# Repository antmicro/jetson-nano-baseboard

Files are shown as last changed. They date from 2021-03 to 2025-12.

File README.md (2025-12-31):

# Jetson Nano Baseboard

Copyright (c) 2020-2025 [Antmicro](https://www.antmicro.com)



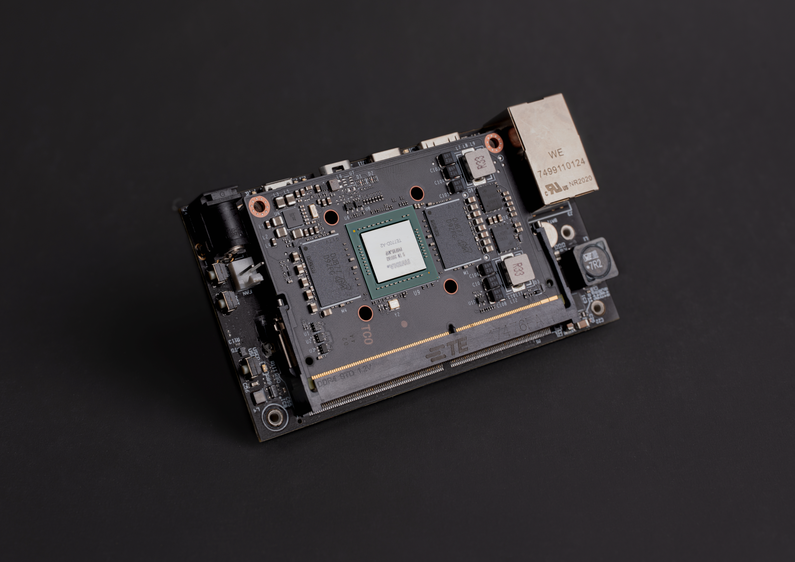
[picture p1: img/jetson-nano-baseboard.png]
Jetson Nano Devboard


## Overview

This project contains open hardware design files for a baseboard supporting the NVIDIA Jetson Nano, Xavier NX and TX2 NX SoMs.
It was created by [Antmicro](https://antmicro.com), a custom hardware, software and AI engineering company and NVIDIA's Jetson ecosystem partner.
The board can be interfaced with MIPI CSI-2 video devices through a unified Flexible Flat Cable (FFC) connector, supporting up to 4 sensors in a 2-lane configuration or 3 sensors in a 4-lane configuration.
Please refer to the Product Design Guide for the relevant SoM for more details regarding the supported CSI lane mappings.
You will find the SoM-related resources in NVIDIA's [Jetson Download Center](https://developer.nvidia.com/embedded/downloads). 

The design files for this project starting from Rev. 1.5 are provided and maintained in KiCad.
Older revisions of the board were prepared in Altium Designer and are kept on a separate [branch](https://github.com/antmicro/jetson-nano-baseboard/tree/1.4.7-altium).

### Project structure:

The main directory contains the KiCad design files, LICENSE and README.
The remaining files are stored in the following directories:

* ``img`` - contains graphics for this README
* ``linux-patches`` - contains patches which add camera support for camera modules from Allied Vision (see the BSP section below)

## Key features

* Jetson Nano / Xavier NX / TX2 NX SO-DIMM connector
* Gigabit Ethernet RJ45 connector
* Micro USB debug connector
* USB-C DFP (Host) port
* Micro HDMI video output interface
* Mini DisplayPort video output interface
* 2x 50-pin FFC connectors exposing up to 4 MIPI CSI-2 camera interfaces
* M.2 (key M) connector exposing PCIe x4 interface
* RTC battery backup
* EEPROM for storing board ID/SN
* 100x55mm (3.93 x 2.16 inch) mechanical outline 

## Getting started

The board can be produced and assembled using the provided design files.
Please take a look at the mechanical layers for more information regarding the PCB stackup recommended for fabrication.
The board can be powered by a voltage in the 6-36VDC range.
It is recommended to use a 12V 2A DC supply to power the board.
The board has an integrated power sequencer that starts the module automatically right after applying power supply.

### BSP

The baseboard's I/O interfaces are supported in the standard [Linux for Tegra (L4T) BSPs](https://developer.nvidia.com/embedded/linux-tegra) provided by NVIDIA for Jetson Nano / Xavier NX / TX2 NX. 
The BSP should work with the Open Source Jetson Baseboard out of the box.
However, to use the baseboard with various cameras and other accessories you may need to make modifications.
If you plan to use the board with Allied Vision [Alvium](https://www.alliedvision.com/en/products/embedded-vision-solutions/alvium-camera-modules-for-embedded-and-machine-vision-applications.html) image sensors, there is a ``linux-patches`` directory, which contains patch files that add support for the Allied Vision cameras for this baseboard with the Jetson Nano NX module.
The patches are named with the L4T release and can be applied to the corresponding branches of the Linux [repository](https://github.com/alliedvision/linux_nvidia_jetson) released by Allied Vision. 
Antmicro's services involve BSP development so you can hire us to make the necessary modifications for you.

You can use the USB OTG interface connector to upload a BSP image to a SoM inserted into the baseboard.

### Debug UART connection

Most of the debug messages are provided through the serial console.
The board includes an FTDI chip providing the UART interface to the host PC.
Please refer to the schematic sheets for more details.
The default debug UART channel is accessible through ``/dev/ttyUSB0`` (assuming that there are no other FTDI units connected to your PC).
The default baudrate for serial debug connection is 115200 baud with an 8-bit transmission, 1 stop bit and with no flow control.

### Revision info

1.5.x revision includes the design files converted into KiCad.
The BOM has been altered so the board can be produced despite the global chip shortage situation.
Revision 1.5.x changes the I2C multiplexer (PCA9548 -> PCA9547) used for handling the cameras and video accessories. 
You may need to adjust the devicetree entries for video accessories to make them work with the new I2C multiplexer chip.

## License

This project is licensed under the [Apache-2.0](LICENSE) license.

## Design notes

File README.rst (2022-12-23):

=======================================
Antmicro's Open Source Jetson Baseboard
=======================================

Copyright (c) 2020-2022 `Antmicro <https://www.antmicro.com>`_





Overview
========

This repository contains open hardware design files for a baseboard supporting the NVIDIA Jetson Nano, Xavier NX and TX2 NX SoMs. It was created by `Antmicro <https://antmicro.com>`_, a custom hardware, software and AI engineering company and NVIDIA's Jetson ecosystem partner.
The board can be interfaced with MIPI CSI-2 video devices through a unified Flexible Flat Cable (FFC) connector, supporting up to 4 sensors in a 2-lane configuration or 3 sensors in a 4-lane configuration.
Please refer to the Product Design Guide for the relevant SoM for more details regarding the supported CSI lane mappings. You will find the SoM-related resources in NVIDIA's `Jetson Download Center <https://developer.nvidia.com/embedded/downloads>`_. 

The baseboard, its custom variants designed by Antmicro per customer's specification, and essential accessories can be purchased from `Capable Robot Components <https://capablerobot.com/products/nx-baseboard/>`_.

The design files for this project starting from Rev. 1.5 are provided and maintained in KiCad.
Older revisions of the board were prepared in Altium Designer and are kept on a separate `branch <https://github.com/antmicro/jetson-nano-baseboard/tree/1.4.7-altium>`_.

Repository structure:
---------------------

The main repository directory contains the KiCad design files, LICENSE and README.
The remaining files are stored in the following directories:

* ``img`` - contains graphics for this README
* ``doc`` - contains generated schematics and other documentation
* ``lib`` - contains KiCad component library
* ``linux-patches`` - contains patches which add camera support for camera modules from Allied Vision (see the BSP section below)

Key features
============

* Jetson Nano / Xavier NX / TX2 NX SO-DIMM connector
* Gigabit Ethernet RJ45 connector
* Micro USB debug connector
* USB-C DFP (Host) port
* Micro HDMI video output interface
* Mini DisplayPort video output interface
* 2x 50-pin FFC connectors exposing up to 4 MIPI CSI-2 camera interfaces
* M.2 (key M) connector exposing PCIe x4 interface
* RTC battery backup
* EEPROM for storing board ID/SN

Getting started
===============

The board can be produced and assembled using the provided design files.
Please take a look at the mechanical layers for more information regarding the PCB stackup recommended for fabrication.
The board can be powered by a voltage in the 6-36VDC range.
It is recommended to use a 12V 2A DC supply to power the board.
The board has an integrated power sequencer that starts the module automatically right after applying power supply.

BSP
---

The baseboard's I/O interfaces are supported in the standard `Linux for Tegra (L4T) BSPs <https://developer.nvidia.com/embedded/linux-tegra>`_ provided by NVIDIA for Jetson Nano / Xavier NX / TX2 NX. The BSP should work with the Open Source Jetson Baseboard out of the box. However, to use the baseboard with various cameras and other accessories you may need to make modifications. If you plan to use the board with Allied Vision `Alvium <https://www.alliedvision.com/en/products/embedded-vision-solutions/alvium-camera-modules-for-embedded-and-machine-vision-applications.html>`_ image sensors, there is a ``linux-patches`` directory, which contains patch files that add support for the Allied Vision cameras for this baseboard with the Jetson Nano NX module.
The patches are named with the L4T release and can be applied to the corresponding branches of the Linux `repository <https://github.com/alliedvision/linux_nvidia_jetson>`_ released by Allied Vision. 
Antmicro's services involve BSP development so you can hire us to make the necessary modifications for you.

You can use the USB OTG interface connector to upload a BSP image to a SoM inserted into the baseboard.

Debug UART connection
---------------------

Most of the debug messages are provided through the serial console.
The board includes an FTDI chip providing the UART interface to the host PC.
Please refer to the schematic sheets for more details.
The default debug UART channel is accessible through ``/dev/ttyUSB0`` (assuming that there are no other FTDI units connected to your PC).
The default baudrate for serial debug connection is 115200 baud with an 8-bit transmission, 1 stop bit and with no flow control.

Revision info
-------------

The latest revision of the board (1.5.x) includes the design files converted into KiCad.
The BOM has been altered so the board can be produced despite the global chip shortage situation.
Revision 1.5.x changes the I2C multiplexer (PCA9548 -> PCA9547) used for handling the cameras and video accessories. You may need to adjust the devicetree entries for video accessories to make them work with the new I2C multiplexer chip.

License
=======

`Apache-2.0 <LICENSE>`_

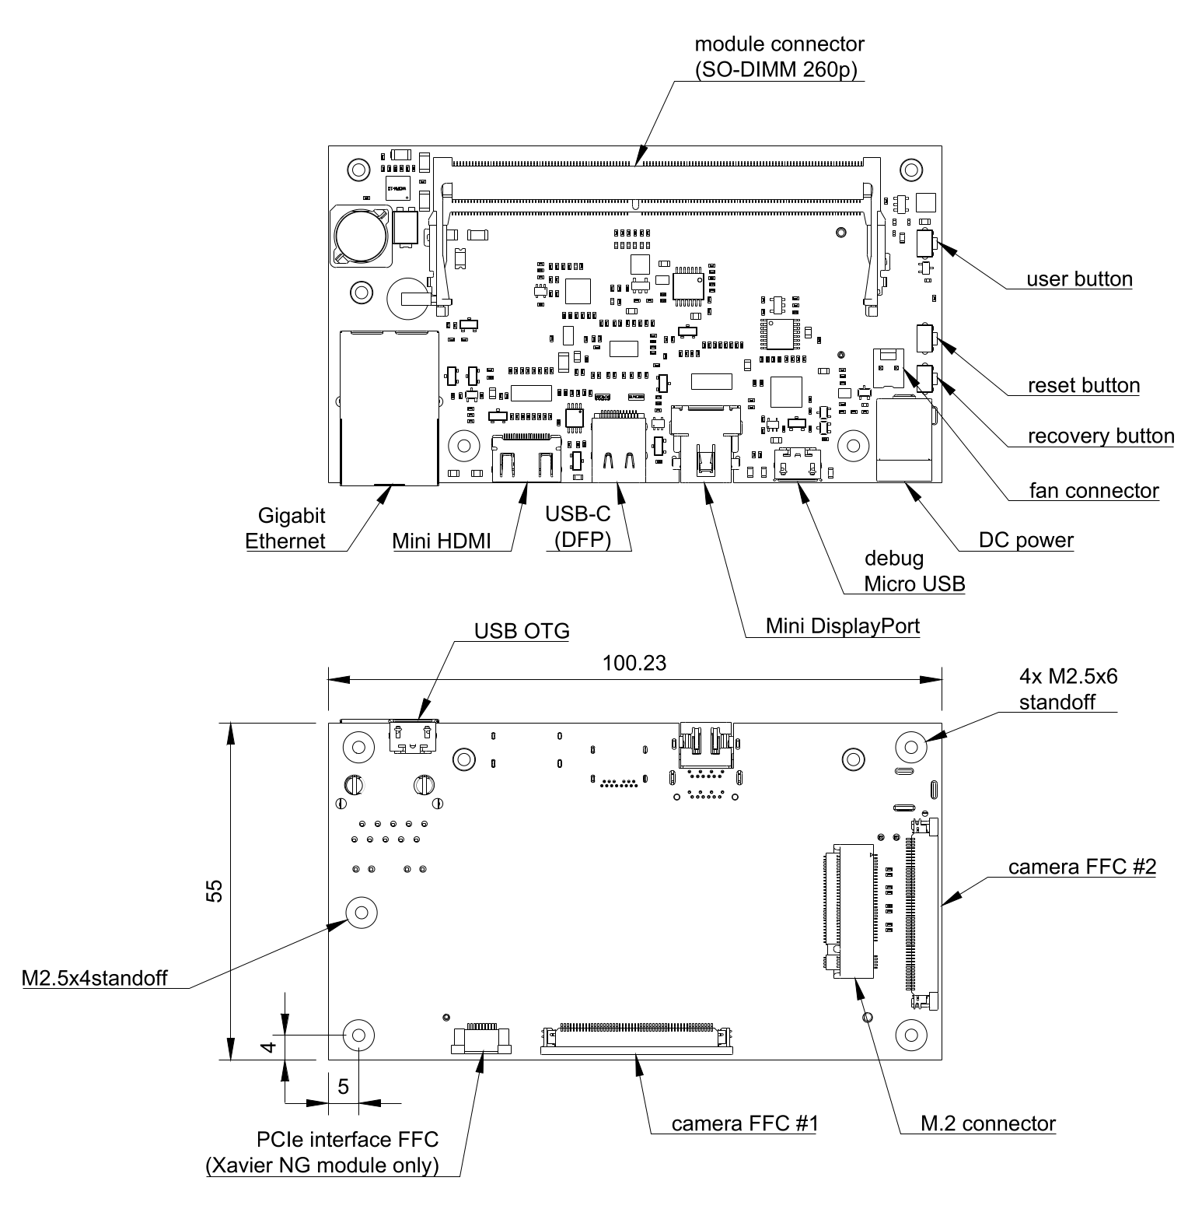
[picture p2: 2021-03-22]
img/jetson-nano-layout.png

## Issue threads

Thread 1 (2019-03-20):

where can find and download this linux system ?

cudnn, 2019-03-20:
where can find and download this linux system ?

pkatarzynski, 2020-04-29:
Most of the IO interfaces available on board are supported by the default BSP provided by Nvidia
See https://developer.nvidia.com/embedded/downloads for more details.

MI-LA01, 2020-11-06:
@pkatarzynski  : Just brought one unit via capable robot for testing. When you said "Most of the IO.." can you elaborate a bit more on that ? What are the IOs not supported by the BSP if any ?

pkatarzynski, 2020-11-06:
You  will most likely need to adjust the BSP for camera (CSI) interfaces. The Ethernet, USB-C, HDMI, Displayport, M.2 (NVMe) are handled by the default JetPack provided by NVIDIA for the Jetson Nano or the Jetson Xavier NX

MI-LA01, 2020-11-06:
Any Guidance/doc to tune the BSP for the 2x 50-pin FFC and 10-pin FFC PCIe x1 ?

Closed 2020-04-29.

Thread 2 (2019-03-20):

how make the usb 3 in device mode?

cudnn, 2019-03-20:
how make the usb 3 in device mode?how pitch the linux kernel ?how reconfigure type c hardwire?

mgielda, 2022-05-07:
I will close this one now - these are very generic questions which are not related to the baseboard itself but rather to Linux/NVIDIA Jetpack. For future reference, we do offer commercial support for customers who need help building software, if you require it please contact us at contact@antmicro.com

Closed 2022-05-07.

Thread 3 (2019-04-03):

PCB files

kfriesth, 2019-04-03:
Would you export the pcb schematic and pcb layout files to kicad or gerber file formats?

qume, 2020-03-17:
Perhaps a bit late, but there is a free online Altium viewer here:

[https://www.altium.com/viewer/](https://www.altium.com/viewer/)

Drag and drop the schdoc files, and it will show you the schematic, the BOM, and in the case of the PCB file, the layout

I'll be starting a KiCAD board for the nano soon, did you end up doing one? Any interest in sharing the project?

pkatarzynski, 2020-04-29:
We have a KiCad version of this board converted from Altium files. We hope to share this version soon.

qume, 2020-04-29:
@pkatarzynski great news, thanks very much. Looking forward to it

AdrianCGonzalez, 2020-06-11:
Would it be possible to export the Altium PCB files to ASCII format?

wgthompson, 2021-03-26:
Longshot but any chance we can get the files in eagle?

wild929, 2021-09-15:
I am using Altium Circuit Studio and am unable to import the PCB layout. Is there a way that you can save the file as  a PCB 5.0 Binary file?

Cheers...

pgielda, 2021-09-15:
Not sure if that helps but there is a branch with Kicad version: https://github.com/antmicro/jetson-nano-baseboard/tree/kicad-version

wild929, 2021-09-15:
> Not sure if that helps but there is a branch with Kicad version: https://github.com/antmicro/jetson-nano-baseboard/tree/kicad-version

Thanks. I am downloading KiCad now in the hopes I can convert the file to PCB Binary 5. I really don't want to have to get up to speed on a new tool.

wild929, 2021-11-08:
Perhaps a bit off topic but can you tell me if the TX2 NX 's USB3 (which is 3.0) and USB1 (2.0) port can be connected directly to a USB3.0 Type A port? Or does this connection require a controller / mux between SOM and port?

Thanks.

pkatarzynski, 2021-11-08:
It is possible to connect the USB lanes you mentioned directly to an USB 3.0 type-A port.

mgielda, 2022-05-07:
As the main branch has switched to KiCad now, this issue can now be closed.

Closed 2022-05-07.

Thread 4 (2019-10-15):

Capacitors on the BOM

S4WRXTTCS, 2019-10-15:
Some of the caps seem to be undersized for the expected voltages.  As an example C1, C2, C3, C4 are shown in the BOM as Murata Electronics P/N: GRM155R60G475ME

That's a 4V part, but C1 along with C2 are connected to HDMI_PWR which has 5V going to it.

Other caps are under the expected voltages, but only barely so. There doesn't seem to be any capacitor de-rating used when creating the BOM.

pkatarzynski, 2019-10-16:
Hi Jason

Thank you for your contribution. We are going to revise the BOM and update the capacitors for a bigger range of rated voltages.

Closed 2019-10-16.

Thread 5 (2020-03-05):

The new PCB doesn't match with the schematic

sunzhongmeng, 2020-03-05:
hello ,i found the new pcb add a M.2 sloat,but the i can't find it in schematics.

pkatarzynski, 2020-03-06:
Hi sunzhongmeng

The M.2 connector (J10) has been defined in interfaces.SchDoc file which has been accidentally excluded from the main project file (PrjPcb). We have fixed the project file.
Thank you for spotting this.

sunzhongmeng, 2020-03-06:
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

Hello Piotr
I fetch the project you have update,yes I see the "Interfaces.SchDoc",I'm sorry to talk about the SD/MMC card,the README file shows the board has a SD/MMC card(the assembly pdf also shows the J8),I didn't see it in the Project files(neither schematics or pcb layout file)

pkatarzynski, 2020-03-06:
This should now be resolved.

Closed 2020-03-06.

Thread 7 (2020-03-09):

HDMI pull down resistors

sunzhongmeng, 2020-03-09:
Hello ，the NVIDIA Jetson Nano Product Designe Guide  says "499Ω, 1% pull-downs must be disabled when Jetson Nano is off or in sleep mode to meet the HDMI VOFF requirement. The enable to the FET, enables the pull-downs when the HDMI interface is to be used"but this design delete all pull down resistors.does it work well?

pkatarzynski, 2020-03-09:
We have simplified some of the interfaces to gain more space for routing and make the PCB smaller. The board is meant to work as technology demonstrator and evaluation platform which stays in always-on mode. Hence satisfying HDMI VOFF was not our priority. The PCBs in rev. 1.3 were displayed at our booth during Embedded World 2020 in [camera related application](https://www.linkedin.com/posts/antmicro-ltd_jetsonnano-xaviernx-opensource-activity-6638028555051638785-Hmo-/)

sunzhongmeng, 2020-03-09:
> We have simplified some of the interfaces to gain more space for routing and make the PCB smaller. The board is meant to work as technology demonstrator and evaluation platform which stays in always-on mode. Hence satisfying HDMI VOFF was not our priority. The PCBs in rev. 1.3 were displayed at our booth during Embedded World 2020 in [camera related application](https://www.linkedin.com/posts/antmicro-ltd_jetsonnano-xaviernx-opensource-activity-6638028555051638785-Hmo-/)

I see ，thank u.

Closed 2020-03-09.

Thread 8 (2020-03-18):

the width of the VIN to TPS54561

sunzhongmeng, 2020-03-18:
The copper of the top layer is 0.035mm,the width of VIN tracks to the TPS54561 is 0.4mm,the power need atlest 5V*4A=20W,so i think the current of VIN is 20W/12V=1.67A,The width seems not enough

pkatarzynski, 2020-03-18:
Hi sunzhongmeng
Thank you for spotting this. We are currently working on rev 1.4 of the design.  The PCB layout has been modified and power distribution planes have been widened accordingly to the expected current density. I hope to update the design files after verification on prototypes.

sunzhongmeng, 2020-03-18:
OK,I got it.because the NX's power dissipation will be 15W,perhaps the +5V supply will more the 5A .

Closed 2020-04-01.

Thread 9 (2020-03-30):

Pin Error of TPD8S009

sunzhongmeng, 2020-03-30:
The VCC pins of the TPD8S009 are Pin 13 and Pin15,not Pin14.

pkatarzynski, 2020-03-30:
Hi sunzhonmeng

You are right, the TPD8S009 chip is still to power supply via pin13 and pin14 (which is effectively a NC pin) in the design so it worked properly on prototypes. Nevertheless the pin to pad assignment in this component needs to be fixed.
Thank you for spotting this.

Closed 2020-04-01.

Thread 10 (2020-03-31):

Power sequensing

gudozhni, 2020-03-31:
Hello!

This might not be an issue, but something in your design contradicts Nvidia information.
It would be great if you could clarify it.
1) The datasheet expressly states that no signals should be applied to any module IO pin until it's completely powered up. To obtain such behavior, the evalkit design enables carrier power supplies (3.3, 1.8) with SYS_RESET, which goes high when module finished power up process. In your design, these power supplies are enabled by POWER_GOOD of the main 5V DC/DC, so they are enabled at the same time as 5V_SYS. You did it like that because it JUST WORKS and you don't see any adverse effect or I'm missing something?
2) According to the graph on the page 9 of the Jetson Nano Product Design Guide, in case of sudden power loss the main power supply should decay from 5V to 3V no faster than at least 10ms, to allow shutting down the module gracefully after servicing SHUTDOWN_REQ and forcing POWER_EN low. The three 47uF caps on the 5V rail in your design would only last for ~50us before the voltage drops to 3V. So the evident question here is - did you have any troubles with hard power offs? Did you test such cases?

I'd be very grateful for any info on the 2 points above!

Best,
Olex

pkatarzynski, 2020-03-31:
Hello Olex

Thank you for your contribution.

As for the 1. this has been already discussed. We are going to release a new PCB revision which uses
SYS_RESET for starting the on-board peripherals. Nevertheless using POWER_GOOD to start the DC/DC worked for us so far as well.

As for 2. we have already done a couple of technology demonstrators using this board. Theese included (multi-) camera setups showcased during the last Embedded World. Most of those setups were powered off by disconnecting the main power supply. This by no means affected the module or software running on it. We will take a look at the voltage decay - we will record this curve on oscilloscope to have a real-life example for further analysis.

gudozhni, 2020-04-01:
Hello Piotr,
thanks a lot for your explanations! that is sufficient for me.

Closed 2020-04-01.

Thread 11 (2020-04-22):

the max dissipation of the nx module

sunzhongmeng, 2020-04-22:
hello,in the latest version i found the supply is tps54561,the max current is 5A,assume the nx module work in 15W model and the USB device need 2A current ,it seems the supply can't provide enouth current.By the way ,dit the new version of the board has been verified?

pkatarzynski, 2020-04-29:
The on-board DC/DC is indeed tailored for 25W. The total power consumption of the Jetson Xavier NX and peripheral interfaces (USB devices or CSI cameras) need to fit within this range. This board is mostly a technology demonstrator. It does not cover all of the possible usage scenarios.
We have tested the prototypes for release 1.4.2. You can check out  our latest blog release in that matter.
https://antmicro.com/blog/2020/04/updated-jetson-nano-xavier-nx-baseboard-m2/
We hope to describe some more integrations soon.

Closed 2020-04-29.

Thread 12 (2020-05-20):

Manufacturing of the board / readily availbale boards for sale?

careyer, 2020-05-20:
Hi there,

thank you very much for taking all the effort and time to make this incredible and compact carrier board. What would be the best way to get one produced (any recommendations of manufacturers that can easily process the available design files?) or maybe is there somebody arround with a ready made spare board that he wants to sell?

Thank you very much and sorry for poluting the issues section =)

sunrise-ceo, 2020-05-22:
Supporting the question above. Would love to buy a couple of ready-made baseboards as well, for testing at first, but, potentially, for mass production of our products. Are there any online retailers (or maybe factories, accepting orders for production) who have this baseboard in stock? Thanks in advance.

kalvdans, 2020-11-09:
Is this fixed by https://github.com/antmicro/jetson-nano-baseboard/commit/56bf3e57818304ef53ff78908ac0a93a50a09229, @pkatarzynski ?

osterwood, 2020-11-17:
Yep!  Baseboards are available for purchase on the Capable Robot website.

https://capablerobot.com/products/nx-baseboard/

Stock on the initial batch is nearly sold out.  A much larger batch is being made now and will take about a month produce.

mgielda, 2020-12-01:
Thanks for answering this, Chris @osterwood :)

Indeed Capable Robot is selling them now, so I consider the issue closed.

Closed 2020-12-01.

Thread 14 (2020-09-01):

buck capacitors for the Jetson NX SOM

sunzhongmeng, 2020-09-01:
the Jetson NX Developer Kit has three capacitors(C145/C146/C147 330uF) for the SOM +5V power supply.But this design just placed two 100uF capacitors (C10/C11),by the way the MLCC has 'DC Bias' character,at +5V the capacitor will be reduce.I have my own carrier board has only two buck capacitors(two 100uF),when i run some programs to test the GPU load the board will be closed(because of the +5V supply droped below 4.75V).

pkatarzynski, 2020-09-11:
We were testing the Jetson Nano Baseboard with NVIDIA Jetson Xavier NX installed and a bunch of benchmarks from https://github.com/NVIDIA-AI-IOT/jetson_benchmarks. This setup worked stable for us.
Please note that the main power supply for the board should be over 5V DC (we have 9V DC suggestion on schematics) to make the on-board DC/DC converter produce 5 VDC required for the SoM.
The board is compact-sized so we are limitted in PCB space available for the filtering capacitors. We are planning to squeeze more of them in the next revision.

Closed 2020-09-27.

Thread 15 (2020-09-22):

Any update on Kicad files?

BlueWaterCrystal, 2020-09-22:
what stage are the Kicad files currently at?

#3
> We have a KiCad version of this board converted from Altium files. We hope to share this version soon.

tkircher, 2020-11-17:
I'd like to know too. I'm interested in a board with this form factor, but stripped down to the SoM connector, DC power, M.2 connector, USB 3.0, and debug port. Would be nice if I could route that in four layers and get it made at OSHpark. ;)

vanbwodonk, 2020-11-19:
I'm waiting for this too.

ncx94, 2021-03-08:
Hi,

Definitely would be interrested in that too!

abhibhatia98, 2021-05-07:
Hello Everyone, I am working on the same project, and completed the schematic and PCB is going to be completed in 2 more days. Any one here who is experienced PCB designer and is interested in this project and who can review my PCB are welcome. I am ready to share project. It will be helpful for other also.

PS: I am not an experienced PCB designer for high speed designs.
Thanks

tkircher, 2021-05-07:
One big advantage of the Jetson SoM is that most of the critical high speed design is done for you.

ncx94, 2021-05-07:
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

Awesome thank you! Not a professional either but I'd be happy to have a look at it! :)

pkatarzynski, 2021-05-07:
We are working on the KiCad version. The design files will be released soon.

ncx94, 2021-07-21:
> We are working on the KiCad version. The design files will be released soon.

Hi,

Any updates on that?

Thanks

pkatarzynski, 2021-08-18:
Please take a look at the branch https://github.com/antmicro/jetson-nano-baseboard/tree/kicad-version

Closed 2021-08-18.

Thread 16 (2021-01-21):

Problem with the HDMI

baroselfdriving, 2021-01-21:
HI. we are working with a modified version of your board adding other peripherals.
We have a problem with the HDMI. The board recognise correctly the MONITOR. But I don't have video, any monitor say: NO SIGNAL. But when I connect the HDMI cable the VNC adjust the resolution automatically with the new monitor.

I review all the design and is the HDMI area is exactly your design.

I installed the last l4t version 4.5 and didn't work. I used the previous and when boot appear not good defined the NVIDIA LOGO. Now I downgrade other version and I can see distorted the image with the initial SETUP of UBUNTU.
Some suggestions?

I'm attaching the dmesg:

27.961495] extcon-disp-state extcon:disp-state: cable 47 state 1
[   27.961501] Extcon AUX1(HDMI) enable
[   27.961902] extcon-disp-state extcon:disp-state: cable 51 state 1
[   27.961905] Extcon HDMI: HPD enabled
[   27.961947] tegradc tegradc.0: hdmi: plugged
[   27.971100] tegradc tegradc.0: blank - powerdown
[   28.026888] extcon-disp-state extcon:disp-state: cable 47 state 0
[   28.026890] Extcon AUX1(HDMI) disable
[   28.047209] tegradc tegradc.0: unblank
[   28.058165] tegradc tegradc.0: nominal-pclk:148500000 parent:148500000 div:1.0 pclk:148500000 147015000~161865000
[   28.058250] tegradc tegradc.0: hdmi: tmds rate:148500K prod-setting:prod_c_hdmi_75m_150m
[   28.059266] tegradc tegradc.0: hdmi: get RGB quant from EDID.
[   28.059273] tegradc tegradc.0: hdmi: get YCC quant from EDID.
[   28.097834] extcon-disp-state extcon:disp-state: cable 47 state 1
[   28.097839] Extcon AUX1(HDMI) enable
[   28.098118] tegradc tegradc.0: unblank
[   28.098125] tegradc tegradc.1: blank - powerdown
[   28.139675] tegradc tegradc.0: unblank
[   28.139834] tegradc tegradc.1: blank - powerdown

Best Regards

Gabriel

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

ahmetcanack, 2021-04-26:
Are you using the correct SOM, I believe there are 2 versions of modules, [You can see the differences here.](https://www.arducam.com/nvidia-jetson-nano-b01-update-dual-camera/)

I have also seen people designing custom carrier boards with the help of the documentation shared by Nvidia.  They were having problems with the ethernet. There is a lot of confusion about this.  Maybe this has to do something with your problem.

Jslater85, 2021-08-18:
Hi, I have encountered similar problems as mentioned  by Gabriel.

Did you ever have any resolution to this issue with the HDMI?

Which SOM is the correct to use?

All the best!

Jake

baroselfdriving, 2021-08-18:
We finally redesign the hdmi lanes to prevent the issue, following the rules of the hdmi design and we used the jetson carrier board to solve many small issues.
About the firmware for 4 cameras, finally we design it based in the e3333 dts in the jetpack and we have it published in our website.

Best regards

Gabriel Giani

pkatarzynski, 2021-08-18:
Hi all, HDMI works properly on the original design and many derivatives we have been building. If you redesign the board yourself and you cannot get something to work on the derivative design, this is not something we can help with. If you need help to build your own board, feel free to reach out to us to use our commercial services.

Closed 2021-08-18.

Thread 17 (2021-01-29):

Routing layers copper pours

iDevMartin, 2021-01-29:
I noticed the signal/routing layers in the layout do not contain large GND copper pours, is there a reason it was not added to the design? Shouldn't it help with impedance control and shielding?

ajawamnet, 2021-04-01:
In some cases it can lead to uncontrolled CPW - coplanar wave guides -
https://en.wikipedia.org/wiki/Coplanar_waveguide

https://www.microwavejournal.com/blogs/1-rog-blog/post/24374-comparing-microstrip-and-grounded-coplanar-waveguide
In the newer versions of altium the simbeor LSM will "sort of" calculate these.   Use of CPW also requires careful consideration of via stiching to the contiguous  reference plane

Regardless, using copper pours is typically not recommended except in certain situations.  As to using it for thieving note what Lee Ritchey states here:
https://ee-training.dk/pcb-manufacturing/copper-thieving-confusion.htm

" If the next layer down is a plane layer,
that is all that is needed. If the next layer down is a signal layer (buried
microstrip) thieving should not be placed over traces in the buried
layer."

I have to agree - I've designed over 3,000 PCB's of various complexities and the only times I've had to use copper pours was for either current requirements or CPW to reduce trace widths to match tiny RF connectors. And the latter is a pain due tot he stitching requirements

Broadcom has a nice, free calculator that has CPW:
https://www.broadcom.com/appcad
This is a later version of the original HP calculator. If you go into the CPW part you can see the effect of having copper pours edge coupling to traces.

And using copper pours on internal layers can lead to split plane issues that cause discontinuities in reference to things like controlled impedance traces - ESP if you are using asymmetric striplines.

mgielda, 2022-05-07:
Since this was explained quite a while ago, I think we can close the issue.

Closed 2022-05-07.

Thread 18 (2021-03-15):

Buffer for driving PWR_EN

yamiyukiharu, 2021-03-15:
Hi, May I know if anyone has tried driving PWR_EN from IC12 instead of IC13?

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

wild929, 2021-12-06:
My understanding of this circuit is that the R84/C41 time constant, and subsequent rise time of the 1A input, is slow enough to make Q = 1 on 5V0_SYS approaching 5V. At this point PWR_EN is latched until #SHUTDOWN_REQ is driven low by the TX2 NX module. Is this correct? What is the purpose of PWR_GOOD? What would be the benefit of driving PWR_EN from IC12 /R130? Response time?

Cheers!

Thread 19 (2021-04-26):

Use of below circuitry

abhibhatia98, 2021-04-26:
Hi I am just looking at your circuit, could you please help me to understand the use of below circuit in supply sheet

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

Thanks
Abhishek

ahmetcanack, 2021-04-26:
Hi, if you look at chapter 5.1 Power Supply and Sequencing in the jetson nano product design guide, you will see a power sequencing graph. Basically, power must not be delivered without control, for some power rails to be enabled, other rails or ok signals must be checked and validated. This circuit makes sure that these enable signals are generated correctly following the power sequencing requirements in the jetson nano product design guideline. I suggest you read the first paragraph in chapter 5.1. There is a nice explanation for all this. And also you might check out how nand gates work. In terms of schematic layout i find this particular layout a bit clustered. But its not impossible to understand. This 4x NAND IC could have been seperated as four individual schematic symbols each showing a NAND symbol. That way it could have been easier for all to read. Lastly this is a great project for individuals to create their custom , and you will find it easier if you go through the product design guide.

abhibhatia98, 2021-04-26:
Thanks for your response, it helps me a lot

Closed 2021-04-26.

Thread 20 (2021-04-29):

Booting board

abhibhatia98, 2021-04-29:
Any specific reasons of removing SD card socket ?

where you will residing your OS ?

ahmetcanack, 2021-04-29:
Jetson Nano SoM has onboard eMMC and sd card socket.

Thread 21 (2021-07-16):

Undetected CSI camera

atoaster, 2021-07-16:
Hi all,

I've been trying to use this board with my IMX219 camera (it works with the Jetson Nano DevKit) to no avail.

My setup is:

Jetson Baseboard [from capablerobots](https://capablerobot.com/products/nx-baseboard/)
15pin flex cable [from capablerobots](https://capablerobot.com/products/nx-baseboard/#tab-flex)
IMX219-AF [from arducam](https://www.arducam.com/product/b0181-arducam-imx219-af-programmable-auto-focus-camera-module-nvidia-jetson-nano/)
Jetson Nano SoM (production module w/emmc)

Am running latest L4T and have installed JetPack via the command line (sudo apt install nvidia-jetpack)

I've got the board setup with the camera connected to Camera FFC 1 (referencing the diagram in the README), but it never gets detected by `nvgstcapture-1.0`. Here's the output from `nvgstcapture-1.0`:

```
<main:4670> iterating capture loop ....
NvMMLiteOpen : Block : BlockType = 4
===== NVMEDIA: NVENC =====
NvMMLiteBlockCreate : Block : BlockType = 4
Error generated. /dvs/git/dirty/git-master_linux/multimedia/nvgstreamer/gst-nvarguscamera/gstnvarguscamerasrc.cpp, execute:645 No cameras available

(nvgstcapture-1.0:6251): GStreamer-CRITICAL **: 13:21:08.592: gst_mini_object_set_qdata: assertion 'object != NULL' failed
```

So clearly it just can't see the connected camera.

Doesn't the 15pin cable effectively simulate the same 15pin connection that the Nano DevKit has? What would I have to do to make it work?

Here are some relevant boot logs from the serial interface:
```

Starting kernel ...

[    0.000000] Booting Linux on physical CPU 0x0
[    0.000000] Linux version 4.9.201-tegra (buildbrain@mobile-u64-5486-d4000) (gcc version 7.3.1 20180425 [linaro-7.3-2018.05 revis1
[    0.000000] Boot CPU: AArch64 Processor [411fd071]
[    0.000000] OF: fdt:memory scan node memory@80000000, reg size 32,
[    0.000000] OF: fdt: - 80000000 ,  7ee00000
[    0.000000] OF: fdt: - 100000000 ,  7f200000
[    0.000000] earlycon: uart8250 at MMIO32 0x0000000070006000 (options '')
[    0.000000] bootconsole [uart8250] enabled
[    1.079141] tegradc tegradc.1: dpd enable lookup fail:-19
[    1.584786] Host read timeout at address 545c00c4
[    1.814808] imx219 7-0010: imx219_board_setup: error during i2c read probe (-121)
[    1.822375] imx219 7-0010: board setup failed
[    1.850550] imx219 8-0010: imx219_board_setup: error during i2c read probe (-121)
[    1.858091] imx219 8-0010: board setup failed
[    2.376727] cgroup: cgroup2: unknown option "nsdelegate"
[    3.427847] using random self ethernet address
[    3.435882] using random host ethernet address
[    3.951725] random: crng init done
[    3.955130] random: 7 urandom warning(s) missed due to ratelimiting
[    3.987257] usb 1-2.4.1: Warning! Unlikely big volume range (=496), cval->res is probably wrong.
[    3.996169] usb 1-2.4.1: [51] FU [Mic Playback Volume] ch = 1, val = 0/7936/16
[    4.010462] usb 1-2.4.1: Warning! Unlikely big volume range (=1008), cval->res is probably wrong.
[    4.019416] usb 1-2.4.1: [49] FU [Speaker Playback Volume] ch = 2, val = -16129/-1/16
[    4.032144] usb 1-2.4.1: Warning! Unlikely big volume range (=496), cval->res is probably wrong.
[    4.041005] usb 1-2.4.1: [50] FU [Mic Capture Volume] ch = 1, val = 0/7936/16
[    4.284504] using random self ethernet address
[    4.289095] using random host ethernet address
[    4.442380] IRQ11 no longer affine to CPU2
[    4.446701] CPU2: shutdown
[    4.514507] IRQ12 no longer affine to CPU3
[    4.519512] CPU3: shutdown
[    6.572823] Bridge firewalling registered
[    6.871576] scsi 0:0:0:0: Direct-Access     NORELSYS 1081             0    PQ: 0 ANSI: 6
[    6.889154] sd 0:0:0:0: [sda] Attached SCSI removable disk
[    7.357459] usb 1-2.4.1: Warning! Unlikely big volume range (=496), cval->res is probably wrong.
[    7.370107] usb 1-2.4.1: [51] FU [Mic Playback Volume] ch = 1, val = 0/7936/16
[    7.390198] usb 1-2.4.1: Warning! Unlikely big volume range (=1008), cval->res is probably wrong.
[    7.406137] usb 1-2.4.1: [49] FU [Speaker Playback Volume] ch = 2, val = -16129/-1/16
[    7.423270] usb 1-2.4.1: Warning! Unlikely big volume range (=496), cval->res is probably wrong.
[    7.435885] usb 1-2.4.1: [50] FU [Mic Capture Volume] ch = 1, val = 0/7936/16

```

Specifically the error looks like:

`[    1.814808] imx219 7-0010: imx219_board_setup: error during i2c read probe (-121)`

kgugala, 2021-07-16:
Hi @atoaster,

One of the differences between the devkit and our board is that on our board the cameras I2C lines are connected through an I2C mux:

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

You need to modify your devicetree to express this. See the patches we provide for Allied Vision cameras. Here https://github.com/antmicro/jetson-nano-baseboard/blob/master/linux-patches/32.4.4.patch#L131 we define the extender and here https://github.com/antmicro/jetson-nano-baseboard/blob/master/linux-patches/32.4.4.patch#L144 we attach the camera driver (as a device one of the child buses of the I2C mux). You need to do similar modification to you DTS and the camera should get detected.

atoaster, 2021-07-21:
Hi @kgugala, thanks for getting back to me!

I don't really know what I'm doing so bear with me...

I'm trying to edit the existing `sources/hardware/nvidia/platform/t19x/jakku/kernel-dts/common/tegra194-camera-rbpcv2-imx219.dtsi` file, since it has the word camera in it.

Since I'm using the 15pin flex cable from CapableRobots, I shouldn't have to change any pin configurations, right? In other words, I should be able to use the regular device tree .dts configuration, but put them behind an `i2c` node (the same one from your av patches)?

Here's the existing dtsi (`tegra194-camera-rbpcv2-imx219.dtsi`):

```
/ {
	host1x {
             ...
	};

	cam_i2cmux {
		i2c_0:i2c@0 {
			imx219_cam0: rbpcv2_imx219_a@10 {
                                ...
			};
		};
		i2c_1: i2c@1 {
			imx219_cam1: rbpcv2_imx219_c@10 {
                                ...
			};
		};
	};
```

I'm going to try this :

```
/ {
	host1x {
                ...
	};
	i2c@3180000 {
                avt_pca9548: avt_pca9548@70 {
			compatible = "nxp,pca9548";
			status = "okay";
			reg = <0x70>;
			#address-cells = <1>;
			#size-cells = <0>;
			vcc-supply = <&battery_reg>;
			force_bus_start = <CAMERA_I2C_MUX_BUS(0)>;
			i2c@2 {
				reg = <2>;
				i2c-mux,deselect-on-exit;
				#address-cells = <1>;
				#size-cells = <0>;
                                imx219_cam0: rbpcv2_imx219_a@10 {
                                        ...
                                }
                       }
               }
       }
}
```
I'm assuming I won't have to do anything to the properties of the `i2c@2` node (hopefully)

Will report back, hopefully this can help anyone else using this board :)

atoaster, 2021-07-26:
Hi @kgugala,

Is the patch meant for the Tegra Xavier SoC? I can't seem to find the `0x3180000` address in the Tegra X1 Technical Reference Manual.

kgugala, 2021-07-29:
Tegra X1 is not meant to work with this baseboard. The patches are for Jetson Xavier NX (see https://github.com/antmicro/jetson-nano-baseboard#bsp)

atoaster, 2021-07-30:
Woops, I was referencing the wrong document! I'm actually using a Jetson Nano.

I've actually gotten the i2cmux working with the following device tree nodes (Apparently the i2c node in the Nano is /host1x/i2c@546c0000)

So now my tree looks like this:
```
    host1x {
		i2c@546c0000 {
			#address-cells = <0x01>;
			#size-cells = <0x00>;
			compatible = "nvidia,tegra210-vii2c";
			reg = <0x00 0x546c0000 0x00 0x34000>;
			iommus = <0x30 0x12>;
			interrupts = <0x00 0x11 0x04>;
			scl-gpio = <0x5b 0x92 0x00>;
			sda-gpio = <0x5b 0x93 0x00>;
			status = "okay";
			clocks = <0x26 0xd0 0x26 0x51 0x26 0x1c>;
			clock-names = "vii2c\0i2cslow\0host1x";
			resets = <0x26 0xd0>;
			reset-names = "vii2c";
			clock-frequency = <0x61a80>;
			bus-pullup-supply = <0x47>;
			avdd_dsi_csi-supply = <0x3b>;
			linux,phandle = <0xad>;
			phandle = <0xad>;

			tca9548@70 {
				compatible = "nxp,pca9548";
				status = "okay";
				reg = <0x70>;
				#address-cells = <1>;
				#size-cells = <0>;
				vcc-supply = <0x4c>;
				force_bus_start = <0x1E>;
				i2c@0 {
					reg = <0>;
					i2c-mux,deselect-on-exit;
					rbpcv2_imx219_a@10 {
						compatible = "nvidia,imx219";
						reg = <0x10>;
						devnode = "video0";
						physical_w = "3.680";
						physical_h = "2.760";
						sensor_model = "imx219";
						use_sensor_mode_id = "true";
						status = "okay";
						reset-gpios = <0x5b 0x97 0x00>;
						linux,phandle = <0xbe>;
						phandle = <0xbe>;
                                                mode0 { ...
                                                };
                                               ...
                                       };
    };
```
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
osterwood, 2021-07-30:
The FFC on the narrow side of the PCB is J7, which has i2c@2 and i2c@3.  The FFC on the long side of the PCB is J6, which has i2c@0 and i2c@1.  If you've connected the 15 pin FFC cable to J7, your imx219 node should be under tca9548@70 -> i2c@2

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

atoaster, 2021-08-02:
@osterwood Thanks for helping me out!

I've now got the camera seemingly being detected, but I'm having a hard time getting it working. It's hitting me with a
```
[    1.843288] imx219 32-0010: i2c bus regbase unavailable
[    1.848560] imx219 32-0010: Could not initialize sensor properties.
[    1.854869] imx219 32-0010: Failed to initialize imx219
[    1.860117] imx219 32-0010: tegra camera driver registration failed

```

I know it's a long shot, but do you have a working `tca9548@70/i2c@x/imx219` dts node that I can copy? I've tried copying the default `imx219` nodes into the `i2c@2` tree and they all seem to throw this exact error.

I feel like the solution is so close!

atoaster, 2021-08-04:
Update: I've finally gotten the DTB working! There was an issue where running a `sudo apt update && sudo apt upgrade` on L4T would replace the DTB, so I had to get it working like follows:

1. Flash Nano
2. copy signed *.dtb from /boot (whichever is relevant to your board version)
3. `sudo apt update && sudo apt upgrade`
4. copy signed dtb back to /boot
5. add FDT /boot/your-custom-device-tree-binary.dtb to the /boot/extlinux/extlinux.conf

But now for some reason `nvgstcapture` will start but it doesn't display the camera feed, not entirely sure why that is, probably has something to do with the DTS I guess

atoaster, 2021-08-04:
Ok, final comment! Looks like `nvgstcapture` doesn't play nice with fps less than 30 sometimes. Here's what I use to display the stream from the camera.

`gst-launch-1.0 nvarguscamerasrc ! 'video/x-raw(memory:NVMM), width=3280, height=2464, format=NV12, framerate=(fraction)21/1' ! nvvidconv ! xvimagesink`

If anyone wants the DTS I used for making an IMX219 work with this baseboard and a Jetson Nano, here ya go:
https://gist.github.com/atoaster/15a533de112f50cc0ee8299dcef8c859

Closed 2021-08-04.

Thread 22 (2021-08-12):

Jetson Xavier NX board boot problem

citrusboy1997, 2021-08-12:
According to your carrier board design, I built a custom version and prototyped the board. Jetson nano module booted successfully on my own board, but Jetson Xavier NX  module didn't. Is Xavier NX not able to boot directly on your design but requires more settings?

osterwood, 2021-08-13:
The published design works with Nano, Xavier NX, and TX2 NX SOMs from NVIDIA.  Without knowing the changes you made it is difficult to know why your design works with a Nano and not the NX.

mgielda, 2021-08-18:
Hi @citrusboy1997, if you redesign the board yourself and you cannot get something to work on the derivative design, this is not something we can help with. If you need help to build your own board or running software on it, feel free to reach out to us to use our commercial services.

Closed 2021-08-18.

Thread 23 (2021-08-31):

Attempting to flash a TX2 NX SoM throws UnicodeDecodeError

atoaster, 2021-08-31:
Hi All, it's me again

I've been toying with using a TX2 NX SoM on your amazing baseboard, but I am getting a UnicodeDecodeError when trying to flash it with the L4T tools.

Here is the full output from `nvautoflash` in JetPack 4.6 (note that this folder was made by the sdkmanager):

```
*** Checking ONLINE mode ... OK.
*** Checking target board connection ... 1 connections found.
*** Reading ECID ... FUSELEVEL=fuselevel_production hwchipid=0x18 bootauth=NS
*** Reading EEPROM ... "/home/atoaster/nvidia/nvidia_sdk/JetPack_4.6_Linux_JETSON_TX2_TARGETS/Linux_for_Tegra/bootloader/tegraflash.py" --chip 0x18 --applet "/home/atoaster/nvidia/nvidia_sdk/JetPack_4.6_Linux_JETSON_TX2_TARGETS/Linux_for_Tegra/bootloader/mb1_recovery_prod.bin" --skipuid --cmd "dump eeprom boardinfo cvm.bin; dump eeprom baseinfo bbd.bin; reboot recovery"
Welcome to Tegra Flash
version 1.0.0
Type ? or help for help and q or quit to exit
Use ! to execute system commands

[   0.0029 ] Generating RCM messages
[   0.0051 ] tegrarcm_v2 --listrcm rcm_list.xml --chip 0x18 0 --download rcm /home/atoaster/nvidia/nvidia_sdk/JetPack_4.6_Linux_JETSON_TX2_TARGETS/Linux_for_Tegra/bootloader/mb1_recovery_prod.bin 0 0
[   0.0062 ] RCM 0 is saved as rcm_0.rcm
[   0.0065 ] RCM 1 is saved as rcm_1.rcm
[   0.0066 ] List of rcm files are saved in rcm_list.xml
[   0.0066 ]
[   0.0066 ] Signing RCM messages
[   0.0093 ] tegrasign_v3.py --key None --list rcm_list.xml --pubkeyhash pub_key.key
[   0.0094 ] Assuming zero filled SBK key
[   0.0167 ] Copying signature to RCM mesages
[   0.0195 ] tegrarcm_v2 --chip 0x18 0 --updatesig rcm_list_signed.xml
[   0.0208 ]
[   0.0209 ] Boot Rom communication
[   0.0231 ] tegrarcm_v2 --chip 0x18 0 --rcm rcm_list_signed.xml --skipuid
[   0.0242 ] RCM version 0X180001
[   0.0253 ] Boot Rom communication completed
[   1.0318 ]
[   2.0365 ] tegrarcm_v2 --isapplet
[   2.0391 ] Applet version 01.00.0000
[   2.0422 ]
[   2.0463 ] Retrieving EEPROM data
[   2.0466 ] tegrarcm_v2 --oem platformdetails eeprom cvm /home/atoaster/nvidia/nvidia_sdk/JetPack_4.6_Linux_JETSON_TX2_TARGETS/Linux_for_Tegra/bootloader/cvm.bin
[   2.0489 ] Applet version 01.00.0000
[   2.0526 ] Saved platform info in /home/atoaster/nvidia/nvidia_sdk/JetPack_4.6_Linux_JETSON_TX2_TARGETS/Linux_for_Tegra/bootloader/cvm.bin
[   2.1251 ]
[   2.1252 ] Generating RCM messages
[   2.1277 ] tegrarcm_v2 --listrcm rcm_list.xml --chip 0x18 0 --download rcm /home/atoaster/nvidia/nvidia_sdk/JetPack_4.6_Linux_JETSON_TX2_TARGETS/Linux_for_Tegra/bootloader/mb1_recovery_prod.bin 0 0
[   2.1288 ] RCM 0 is saved as rcm_0.rcm
[   2.1293 ] RCM 1 is saved as rcm_1.rcm
[   2.1294 ] List of rcm files are saved in rcm_list.xml
[   2.1294 ]
[   2.1294 ] Signing RCM messages
[   2.1326 ] tegrasign_v3.py --key None --list rcm_list.xml --pubkeyhash pub_key.key
[   2.1327 ] Assuming zero filled SBK key
[   2.1417 ] Copying signature to RCM mesages
[   2.1444 ] tegrarcm_v2 --chip 0x18 0 --updatesig rcm_list_signed.xml
[   2.1464 ]
[   2.1465 ] Boot Rom communication
[   2.1491 ] tegrarcm_v2 --chip 0x18 0 --rcm rcm_list_signed.xml
[   2.1504 ] BootRom is not running
[   7.4048 ]
[   8.4108 ] tegrarcm_v2 --isapplet
[   8.4139 ] Applet version 01.00.0000
[   8.4173 ]
[   8.4218 ] Retrieving EEPROM data
[   8.4221 ] tegrarcm_v2 --oem platformdetails eeprom cvb /home/atoaster/nvidia/nvidia_sdk/JetPack_4.6_Linux_JETSON_TX2_TARGETS/Linux_for_Tegra/bootloader/bbd.bin
[   8.4250 ] Applet version 01.00.0000
[   8.4435 ] 00Traceback (most recent call last):
  File "/home/atoaster/nvidia/nvidia_sdk/JetPack_4.6_Linux_JETSON_TX2_TARGETS/Linux_for_Tegra/bootloader/tegraflash.py", line 1296, in <module>
    tegraflash_run_commands()
  File "/home/atoaster/nvidia/nvidia_sdk/JetPack_4.6_Linux_JETSON_TX2_TARGETS/Linux_for_Tegra/bootloader/tegraflash.py", line 1155, in tegraflash_run_commands
    interpreter.onecmd(command)
  File "/usr/lib/python3.9/cmd.py", line 217, in onecmd
    return func(arg)
  File "/home/atoaster/nvidia/nvidia_sdk/JetPack_4.6_Linux_JETSON_TX2_TARGETS/Linux_for_Tegra/bootloader/tegraflash.py", line 785, in do_dump
    tegraflash_dump(exports, args)
  File "/home/atoaster/nvidia/nvidia_sdk/JetPack_4.6_Linux_JETSON_TX2_TARGETS/Linux_for_Tegra/bootloader/tegraflash_internal.py", line 1370, in tegraflash_dump
    tegraflash_dumpeeprom(args, dump_args[1:])
  File "/home/atoaster/nvidia/nvidia_sdk/JetPack_4.6_Linux_JETSON_TX2_TARGETS/Linux_for_Tegra/bootloader/tegraflash_internal.py", line 1448, in tegraflash_dumpeeprom
    run_command(command)
  File "/home/atoaster/nvidia/nvidia_sdk/JetPack_4.6_Linux_JETSON_TX2_TARGETS/Linux_for_Tegra/bootloader/tegraflash_internal.py", line 202, in run_command
    log = print_process(process, enable_print)
  File "/home/atoaster/nvidia/nvidia_sdk/JetPack_4.6_Linux_JETSON_TX2_TARGETS/Linux_for_Tegra/bootloader/tegraflash_internal.py", line 178, in print_process
    for string in process.communicate()[0].decode('utf-8').split('\n'):
UnicodeDecodeError: 'utf-8' codec can't decode byte 0xa4 in position 16: invalid start byte
--- Error: Reading board information failed.

```

I've gone down the Nvidia Forum rabbit hole and it led me [here](https://forums.developer.nvidia.com/t/invalid-start-byte-when-flashing-tx2-nx-on-custom-board/185998/3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), indicating I need some kinda board configuration file "from the vendor".

Does this file exist anywhere? Or do I need to make it? Has anyone succeeded in flashing JetPack 4.6 on a TX2 NX SoM with this baseboard?

osterwood, 2021-08-31:
I've not tested 4.6, but the CLI workflow does work for 4.5.1 (e.g L4T 32.5.1).

```
wget https://developer.nvidia.com/embedded/l4t/r32_release_v5.1/r32_release_v5.1/t186/tegra186_linux_r32.5.1_aarch64.tbz2
wget https://developer.nvidia.com/embedded/l4t/r32_release_v5.1/r32_release_v5.1/t186/tegra_linux_sample-root-filesystem_r32.5.1_aarch64.tbz2

export L4T_RELEASE_PACKAGE='tegra186_linux_r32.5.1_aarch64.tbz2'
export SAMPLE_FS_PACKAGE='tegra_linux_sample-root-filesystem_r32.5.1_aarch64.tbz2'

tar xvf ${L4T_RELEASE_PACKAGE}
cd Linux_for_Tegra/rootfs/
sudo tar xvpf ../../${SAMPLE_FS_PACKAGE}
cd ..

sudo ./apply_binaries.sh
sudo ./flash.sh jetson-xavier-nx-devkit-tx2-nx internal
```

I can try the above with the proper links for 4.6, but likely not in the next day or two.  If you want to attempt, the L4T archive has the URLs:

https://developer.nvidia.com/embedded/jetpack-archive
https://developer.nvidia.com/embedded/linux-tegra-r3261

atoaster, 2021-08-31:
Welp, just tried 4.5.1 using the `sdkmanager` and it worked fine, whereas 4.6 did not.

I guess it's just something to do with 4.6 specifically?

Will leave this issue open if you find anything but otherwise my problem is solved by just using 4.5.1 :)

Closed 2023-03-11.

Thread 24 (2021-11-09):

USB C not working at boot

vdsmax, 2021-11-09:
Hi, I have an issue with the USB C from the board. When I boot my Xavier NX card with the board, I am not able to use a keyboard or a mouse. The card seems to boot normaly and I have the hdmi port which is working.
How can I available the USB C to work on boot ?
I am able to debug the board through an ssh connection.
The Xavier NX card works well on the development kit.

Here are the logs with the dmesg command. It seems that the USB C is working at the beginning of the boot (1.837254), then it is closed (11.972174):

[    0.000000] Booting Linux on physical CPU 0x0
[    0.000000] Linux version 4.9.140-tegra (buildbrain@mobile-u64-3357) (gcc version 7.3.1 20180425 [linaro-7.3-2018.05 revision d29120a424ecfbc167ef90065c0eeb7f91977701] (Linaro GCC 7.3-2018.05) ) #1 SMP PREEMPT Thu Jun 25 21:22:12 PDT 2020
[    0.000000] Boot CPU: AArch64 Processor [4e0f0040]
[    0.000000] OF: fdt:memory scan node memory, reg size 48,
[    0.000000] OF: fdt: - 80000000 ,  2c000000
[    0.000000] OF: fdt: - ac200000 ,  44600000
[    0.000000] OF: fdt: - 100000000 ,  180000000
[    0.000000] earlycon: tegra_comb_uart0 at MMIO32 0x000000000c168000 (options '')
[    0.000000] bootconsole [tegra_comb_uart0] enabled
[    0.000000] Found tegra_fbmem: 00140000@a069c000
[    0.000000] Found lut_mem: 00002008@a0696000
[    0.000000] OF: fdt:Reserved memory: failed to reserve memory for node 'fb1_carveout': base 0x0000000000000000, size 0 MiB
[    0.000000] OF: fdt:Reserved memory: failed to reserve memory for node 'fb1_carveout': base 0x0000000000000000, size 0 MiB
[    0.000000] OF: fdt:Reserved memory: failed to reserve memory for node 'fb2_carveout': base 0x0000000000000000, size 0 MiB
[    0.000000] OF: fdt:Reserved memory: failed to reserve memory for node 'fb2_carveout': base 0x0000000000000000, size 0 MiB
[    0.000000] OF: fdt:Reserved memory: failed to reserve memory for node 'fb3_carveout': base 0x0000000000000000, size 0 MiB
[    0.000000] OF: fdt:Reserved memory: failed to reserve memory for node 'fb3_carveout': base 0x0000000000000000, size 0 MiB
[    0.000000] OF: reserved mem: initialized node ramoops_carveout, compatible id nvidia,ramoops
[    0.000000] OF: reserved mem: initialized node vpr-carveout, compatible id nvidia,vpr-carveout
[    0.000000] OF: reserved mem: initialized node grid-of-semaphores, compatible id nvidia,gosmem
[    0.000000] cma: Reserved 64 MiB at 0x00000000c2000000
[    0.000000] On node 0 totalpages: 2032317
[    0.000000]   DMA zone: 7179 pages used for memmap
[    0.000000]   DMA zone: 0 pages reserved
[    0.000000]   DMA zone: 459453 pages, LIFO batch:31
[    0.000000]   Normal zone: 24576 pages used for memmap
[    0.000000]   Normal zone: 1572864 pages, LIFO batch:31
[    0.000000] psci: probing for conduit method from DT.
[    0.000000] psci: PSCIv1.0 detected in firmware.
[    0.000000] psci: Using standard PSCI v0.2 function IDs
[    0.000000] psci: MIGRATE_INFO_TYPE not supported.
[    0.000000] psci: SMC Calling Convention v1.1
[    0.000000] percpu: Embedded 25 pages/cpu @ffffffc1ffd05000 s61656 r8192 d32552 u102400
[    0.000000] pcpu-alloc: s61656 r8192 d32552 u102400 alloc=25*4096
[    0.000000] pcpu-alloc: [0] 0 [0] 1 [0] 2 [0] 3 [0] 4 [0] 5
[    0.000000] Speculative Store Bypass Disable mitigation not required
[    0.000000] Built 1 zonelists in Zone order, mobility grouping on.  Total pages: 2000562
[    0.000000] Kernel command line: console=ttyTCU0,115200 video=tegrafb no_console_suspend=1 earlycon=tegra_comb_uart,mmio32,0x0c168000 gpt tegra_fbmem=0x140000@0xa069c000 lut_mem=0x2008@0xa0696000 usbcore.old_scheme_first=1 tegraid=19.1.2.0.0 maxcpus=6 boot.slot_suffix=_b boot.ratchetvalues=0.4.2 vpr_resize sdhci_tegra.en_boot_part_access=1    quiet root=/dev/mmcblk0p1 rw rootwait rootfstype=ext4 console=ttyTCU0,115200n8 console=tty0 fbcon=map:0 net.ifnames=0
[    0.000000] log_buf_len individual max cpu contribution: 32768 bytes
[    0.000000] log_buf_len total cpu_extra contributions: 163840 bytes
[    0.000000] log_buf_len min size: 32768 bytes
[    0.000000] log_buf_len: 262144 bytes
[    0.000000] early log buf free: 29176(89%)
[    0.000000] PID hash table entries: 4096 (order: 3, 32768 bytes)
[    0.000000] Dentry cache hash table entries: 1048576 (order: 11, 8388608 bytes)
[    0.000000] Inode-cache hash table entries: 524288 (order: 10, 4194304 bytes)
[    0.000000] Memory: 7189096K/8129268K available (15294K kernel code, 2934K rwdata, 6640K rodata, 8576K init, 609K bss, 186508K reserved, 753664K cma-reserved)
[    0.000000] Virtual kernel memory layout:
[    0.000000]     modules : 0xffffff8000000000 - 0xffffff8008000000   (   128 MB)
[    0.000000]     vmalloc : 0xffffff8008000000 - 0xffffffbebfff0000   (   250 GB)
[    0.000000]       .text : 0xffffff8008080000 - 0xffffff8008f70000   ( 15296 KB)
[    0.000000]     .rodata : 0xffffff8008f70000 - 0xffffff8009600000   (  6720 KB)
[    0.000000]       .init : 0xffffff8009600000 - 0xffffff8009e60000   (  8576 KB)
[    0.000000]       .data : 0xffffff8009e60000 - 0xffffff800a13d808   (  2935 KB)
[    0.000000]        .bss : 0xffffff800a13d808 - 0xffffff800a1d5f7c   (   610 KB)
[    0.000000]     fixed   : 0xffffffbefe7fd000 - 0xffffffbefec00000   (  4108 KB)
[    0.000000]     PCI I/O : 0xffffffbefee00000 - 0xffffffbeffe00000   (    16 MB)
[    0.000000]     vmemmap : 0xffffffbf00000000 - 0xffffffc000000000   (     4 GB maximum)
[    0.000000]               0xffffffbf00000000 - 0xffffffbf08000000   (   128 MB actual)
[    0.000000]     memory  : 0xffffffc000000000 - 0xffffffc200000000   (  8192 MB)
[    0.000000] SLUB: HWalign=64, Order=0-3, MinObjects=0, CPUs=6, Nodes=1
[    0.000000] Preemptible hierarchical RCU implementation.
[    0.000000] 	Build-time adjustment of leaf fanout to 64.
[    0.000000] 	RCU restricting CPUs from NR_CPUS=64 to nr_cpu_ids=6.
[    0.000000] RCU: Adjusting geometry for rcu_fanout_leaf=64, nr_cpu_ids=6
[    0.000000] NR_IRQS:64 nr_irqs:64 0
[    0.000000] GIC: Using split EOI/Deactivate mode
[    0.000000] arm_arch_timer: Architected cp15 timer(s) running at 31.25MHz (phys).
[    0.000000] clocksource: arch_sys_counter: mask: 0xffffffffffffff max_cycles: 0xe6a171046, max_idle_ns: 881590405314 ns
[    0.000005] sched_clock: 56 bits at 31MHz, resolution 32ns, wraps every 4398046511088ns
[    0.000929] Console: colour dummy device 80x25
[    0.000941] console [tty0] enabled
[    0.000949] bootconsole [tegra_comb_uart0] disabled
[    0.000961] kmemleak: Kernel memory leak detector disabled
[    0.000979] Calibrating delay loop (skipped), value calculated using timer frequency.. 62.50 BogoMIPS (lpj=125000)
[    0.000995] pid_max: default: 32768 minimum: 301
[    0.002074] Security Framework initialized
[    0.002637] Mount-cache hash table entries: 16384 (order: 5, 131072 bytes)
[    0.002647] Mountpoint-cache hash table entries: 16384 (order: 5, 131072 bytes)
[    0.004227] ftrace: allocating 47104 entries in 185 pages
[    0.395760] sched-energy: Sched-energy-costs installed from DT
[    0.395780] ASID allocator initialised with 65536 entries
[    0.431246] tegra-id: chipid=21917.
[    0.431258] tegra-id: opt_subrevision=1.
[    0.431289] Tegra Revision: A02 SKU: 0xde CPU Process: 0 SoC Process: 0
[    0.431302] DTS File Name: /dvs/git/dirty/git-master_linux/kernel/kernel-4.9/arch/arm64/boot/dts/../../../../../../hardware/nvidia/platform/t19x/jakku/kernel-dts/tegra194-p3668-all-p3509-0000.dts
[    0.431312] DTB Build time: Jun 25 2020 21:27:47
[    0.479210] CPU1: Booted secondary processor [4e0f0040]
[    0.511394] CPU2: Booted secondary processor [4e0f0040]
[    0.543510] CPU3: Booted secondary processor [4e0f0040]
[    0.575743] CPU4: Booted secondary processor [4e0f0040]
[    0.607773] CPU5: Booted secondary processor [4e0f0040]
[    0.608008] Brought up 6 CPUs
[    0.608047] SMP: Total of 6 processors activated.
[    0.608063] CPU features: detected feature: Privileged Access Never
[    0.608069] CPU features: detected feature: LSE atomic instructions
[    0.608076] CPU features: detected feature: User Access Override
[    0.608082] CPU features: detected feature: 32-bit EL0 Support
[    0.609554] CPU: All CPU(s) started at EL2
[    0.609603] alternatives: patching kernel code
[    0.616153] devtmpfs: initialized
[    0.652422] Initilizing CustomIPI irq domain
[    0.652715] clocksource: jiffies: mask: 0xffffffff max_cycles: 0xffffffff, max_idle_ns: 7645041785100000 ns
[    0.652731] futex hash table entries: 2048 (order: 5, 131072 bytes)
[    0.677027] pinctrl core: initialized pinctrl subsystem
[    0.677305] OS set in device tree is not L4T.
[    0.677563] regulator-dummy: no parameters
[    0.677784] Initializing plugin-manager
[    0.677838] Plugin module not found
[    0.677885] Plugin-manager status disabled
[    0.679085] NET: Registered protocol family 16
[    0.680236] pstore: using zlib compression
[    0.680257] console [pstore-1] enabled
[    0.680262] pstore: Registered ramoops as persistent store backend
[    0.680268] ramoops: attached 0x200000@0xf0600000, ecc: 0/0
[    0.694694] cpuidle: using governor menu
[    0.695788] bpmp: waiting for handshake
[    0.695795] bpmp: handshake completed
[    0.695809] bpmp: synchronizing channels
[    0.695818] bpmp: channels synchronized
[    0.695824] bpmp: mail init ok
[    0.698269] t19x-arm-smmu 12000000.iommu: found 3 SMMUs and ISO SMMU id is 2
[    0.698430] t19x-arm-smmu 12000000.iommu: probing hardware configuration...
[    0.698437] t19x-arm-smmu 12000000.iommu: SMMUv2 with:
[    0.698443] t19x-arm-smmu 12000000.iommu: 	stage 1 translation
[    0.698449] t19x-arm-smmu 12000000.iommu: 	stage 2 translation
[    0.698454] t19x-arm-smmu 12000000.iommu: 	nested translation
[    0.698465] t19x-arm-smmu 12000000.iommu: 	stream matching with 128 register groups, mask 0x7f80
[    0.698496] t19x-arm-smmu 12000000.iommu: SMMU address space size (0x800000) differs from mapped region size (0x1000000)!
[    0.698504] t19x-arm-smmu 12000000.iommu: 	64 context banks (0 stage-2 only)
[    0.698511] t19x-arm-smmu 12000000.iommu: 	Stage-1: 39-bit VA -> 48-bit IPA
[    0.698519] t19x-arm-smmu 12000000.iommu: 	Stage-2: 39-bit IPA -> 48-bit PA
[    0.701578] vdso: 2 pages (1 code @ ffffff8008f77000, 1 data @ ffffff8009e64000)
[    0.701603] hw-breakpoint: found 6 breakpoint and 4 watchpoint registers.
[    0.704207] atomic_pool_init():622: DMA: preallocated 1024 KiB pool for atomic allocations
[    0.705399] tegra_aon_clk_init: ok
[    0.705409] Registering BPMP clocks...
[    0.705500] tegra_bpmp_clk_init: clock init ok (400 clks)
[    0.706019] Serial: AMBA PL011 UART driver
[    0.706162] tegra_powergate_init: DONE
[    0.706237] DTS File Name: /dvs/git/dirty/git-master_linux/kernel/kernel-4.9/arch/arm64/boot/dts/../../../../../../hardware/nvidia/platform/t19x/jakku/kernel-dts/tegra194-p3668-all-p3509-0000.dts
[    0.706249] DTB Build time: Jun 25 2020 21:27:47
[    0.708871] Tegra reboot handler registered.
[    0.716243] iommu: Adding device 14160000.pcie to group 0
[    0.716847] iommu: Adding device 141a0000.pcie to group 1
[    0.718273] iommu: Adding device 2490000.ether_qos to group 2
[    0.718734] iommu: Adding device 3100000.serial to group 3
[    0.719258] iommu: Adding device 3110000.serial to group 4
[    0.719640] iommu: Adding device 3140000.serial to group 5
[    0.720262] tegra-pmc c360000.pmc: scratch reg offset dts data not present
[    0.720601] tegra-pmc: get_secure_pmc_setting: done secure_pmc=0
[    0.720624] tegra-pmc: ### PMC reset source: TEGRA_POWER_ON_RESET
[    0.720631] tegra-pmc: ### PMC reset level: TEGRA_RESET_LEVEL_L0
[    0.720639] tegra-pmc: ### PMC reset status reg: 0x0
[    0.720687] tegra-pmc: PMC Prod config success
[    0.720919] padctrl padctrl.0: Pad control driver tegra-pmc-padctrl registered
[    0.720958] tegra-pmc c360000.pmc: IO padctrl driver initialized
[    0.721274] iommu: Adding device 3400000.sdhci to group 6
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

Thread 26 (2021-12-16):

Generate Gerber files

outbackdingo, 2021-12-16:
Hi hate to ask can someone please generate valid gerber files for me, im having an issue and not sure why, id like to produce this board for a prototype.

Closed 2025-02-24.

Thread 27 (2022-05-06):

only one M.2 ?  how use wifi module

zouzhe1, 2022-05-06:
only one M.2 ?  how use wifi module.
and other 4G module

mgielda, 2022-05-07:
Hi @zouzhe1 the board was designed with size in mind, so it has one M.2 slot. Additional components can be integrated over USB, the other PCIe (on Xavier NX), or by customizing the design, which is a service we offer.

Closed 2022-05-07.

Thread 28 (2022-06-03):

Support for later versions of Jetpack?

BlueprintLab-s-hall, 2022-06-03:
Hi Ant Micro

My company has recently designed and produced a prototype custom carrier board based on your open source jetson baseboard. It has two MIPI CSI-2 ports on it that we are using to connect two Allied Vision 1800-C158C cameras. We are using a TX2 NX module in the carrier board. Unfortunately, Allied Vision's driver software is still in beta for the TX2 NX and only supports Jetpack 4.6.1 (l4t-32.7.1). I'm writing to ask whether support for Jetpack 4.6.1 (or other versions) is available somewhere or in development?
If not, is there a way we can work together to produce one?

Best regards

TJMolnar, 2022-10-28:
Hi,

Is there any update on this? I am very interested in using these boards with our Allied Vision cameras, but only if there is support for them with the current Allied Vision driver releases (Jetpack 4.6.1 or newer)

Thanks.

(tagging @tgorochowik as they committed the original patches)

tgorochowik, 2022-11-30:
We've added some patches for 32.7.2 here, for example for tx2 nx here: https://github.com/antmicro/jetson-nano-baseboard/blob/8ebbd8620282d0c63678a6a6b43d9a2abe7f230b/linux-patches/lanai-l4t-32.7.2-add-support-for-JNB-rev.1.5.1.patch

Note that this is currently the newest release that supports TX2 NX.

@TJMolnar There is no reason why this board wouldn't work with Jetpack 5.0.2 with AV cameras, but we don't have patches for that as we didn't need those yet. The boards have been used with non-av cameras and newest jetpack though.

I am closing this as there is another issue opened that asks specifically for Jetpack 5.0

Closed 2022-11-30.

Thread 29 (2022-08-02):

Compatibility with Older Jetson nano modules

radiumWater256, 2022-08-02:
Hello. I have a Jetson Nano devkit module (revision A02) and wish to find a carrier board for it. Is this carrier board design compatible with the older modules? Thanks.

osterwood, 2022-08-09:
The revision A Nano dev kit modules use a different pin out than the published one by NVIDIA and as such will not work with this baseboard.  Revision B (and later) are okay, but A will not work.  Sorry.

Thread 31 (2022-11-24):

Tx2/Nano differences on carrier based on this open source board.

wild929, 2022-11-24:
Thank you for contributing to this project. It has been educational and very helpful.

This is a long shot but I am curious if anyone has any ideas on this problem.
I designed a carrier based on this open-source board with some additional sensors. I also removed some interfaces I did not need. This board has worked reliably with the Jetson Nano module and all interfaces (HDMI, Ethernet, CSI, USB) have never presented an issue. I have 8 of them working in the field with no problems. I recently revised this PCB to include an SD card in order to work with the TX2NX.

To be brief, The Nano modules work with ver1 and ver 2 of this board. The TX2 NX modules work with ver1 but will not boot up on ver2. There are a variety of errors with some specifying emmc issues (emmc is module level and not on the carrier).

Has anyone had any boot up issues using TX2NX modules on carriers based on this design.? Any insights on why the same TX2 modules would work with Ver 1 but not Ver 2, when they are the same except for an SD card interface?

rem0nz, 2022-11-25:
@wild929 , how can I reach you for some work ?

wild929, 2022-11-28:
You can reach me at contact@iltmicrosystems.com

Cheers!

> @wild929 , how can I reach you for some work ?

Closed 2022-11-28.

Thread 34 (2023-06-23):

Missing BOM parts incomplete

karthikbalu, 2023-06-23:
Great project, Please give us the latest BOM currently we find many part numbers are missing
Thanks

Closed 2025-02-24.

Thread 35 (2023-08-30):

Flashing Fails

david-rse, 2023-08-30:
Hello,

I've tried flashing with SDKM using JetPack 4.6.4 and the process hangs and never finishes, the last line in the console is:

```Saved platform info in storage_info.bin```

Manually flashing, I'm getting a false-positive success. Using:

``` sudo ./flash.sh jetson-nano-qspi mmcblk0p1```

the process completes with:

```
*** The target t210ref has been flashed successfully. ***
Reset the board to boot from the internal eMMC.
```

However, upon reboot the OS is not loading and it's stuck on the NVIDIA logo splash screen.

Any advice or further info on the flash procedure would be greatly appreciated.

Thank you,
Dave

Closed 2023-08-30.

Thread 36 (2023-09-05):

Problem with SSD

jarjaf, 2023-09-05:
Hello, I have a problem with SSD write speed. The Samsung 980 PRO SSD supports writing up to 2700 MB/s, but tests show 333 MB/s. For us, write speed is very critical. Could this be related to the board?

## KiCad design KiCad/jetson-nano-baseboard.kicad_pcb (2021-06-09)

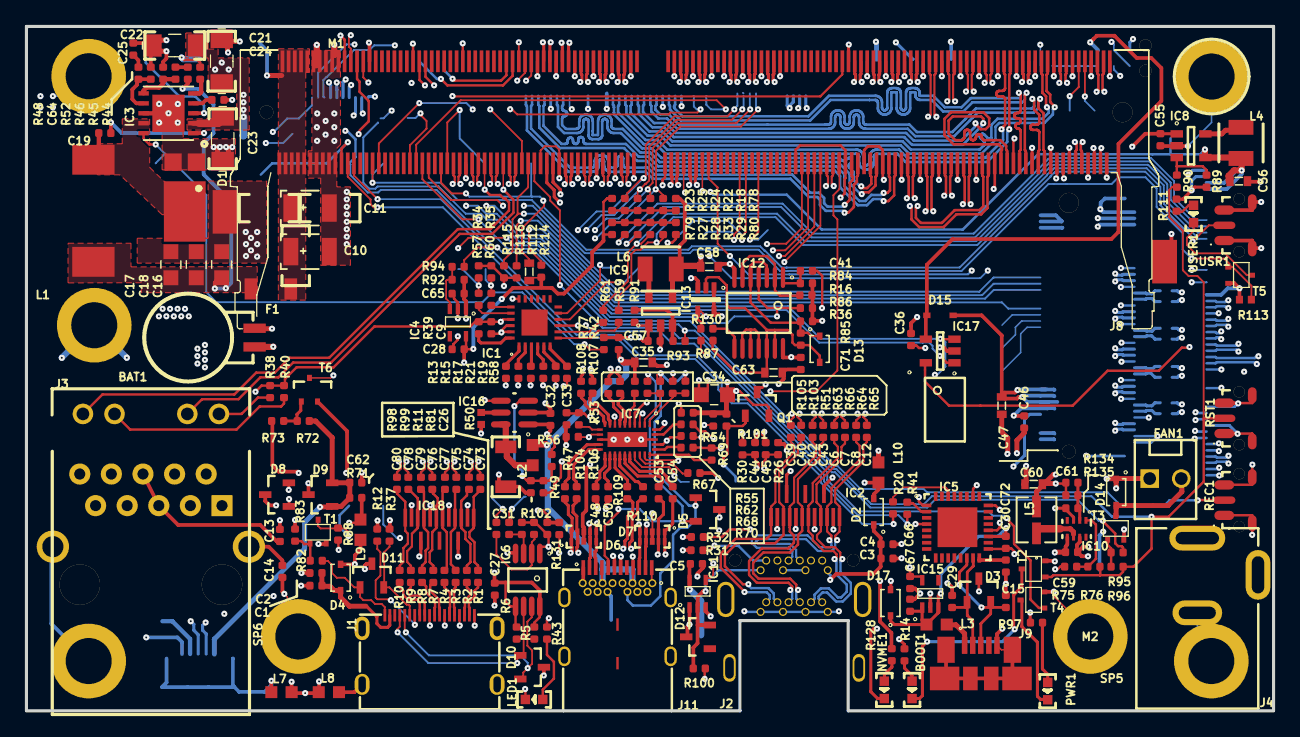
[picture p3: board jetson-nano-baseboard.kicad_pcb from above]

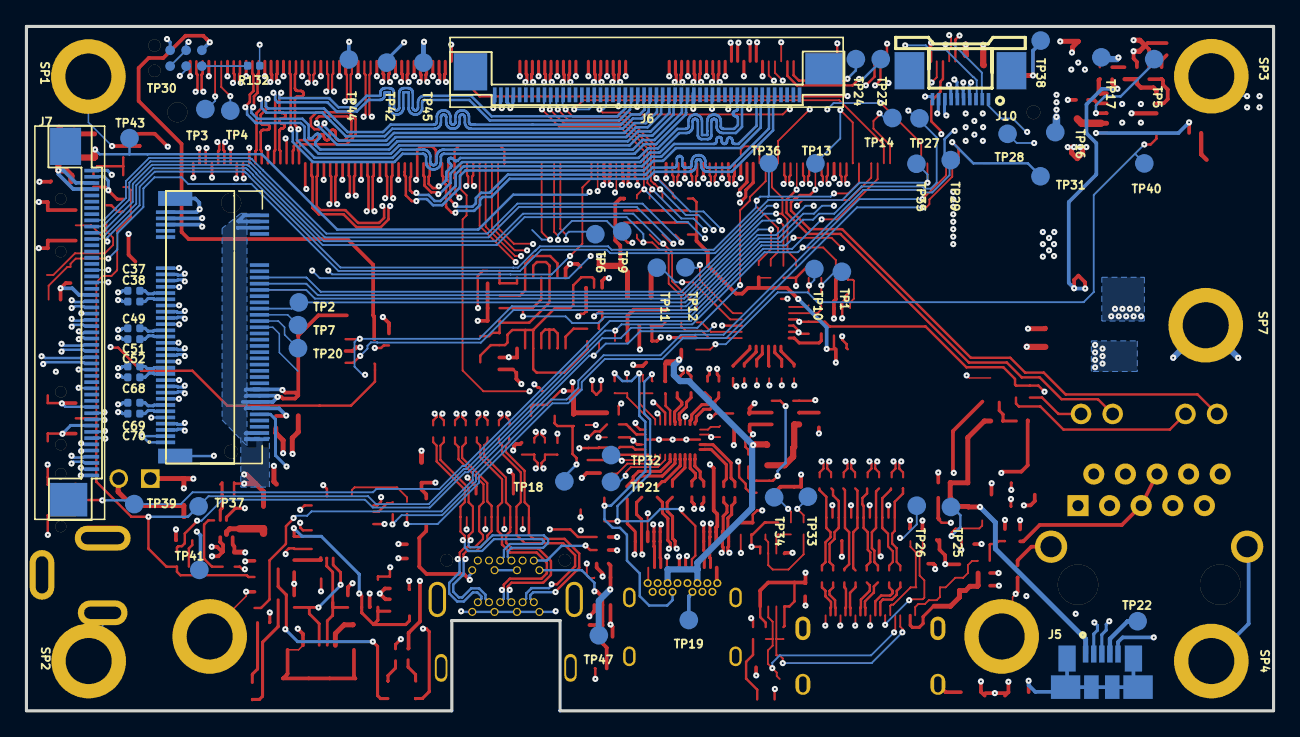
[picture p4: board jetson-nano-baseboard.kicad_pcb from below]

Board: 8 copper layers, 100.2 x 55.0 mm, 325 parts (63 on the bottom side), 312 nets.

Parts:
BAT1: MS621FE-FL11E
BOOT1: LED0603
C1, C2, C3, C4, C62: C_4u7_0402; 0402-cap
C5, C6, C7, C8, C9, C12, C19, C26, C27, C30, C33, C36, C37, C38, C39, C40, C42, C43, C44, C45, C46, C48, C49, C50, C51, C52, C53, C54, C68, C69, C70, C71, C72, C73, C74, C75, C76, C77, C78, C79, C80: C_100n_0402; 0402-cap
C10, C11: C_330u_KEMET_B; KEMET_B
C13, C24: C_10n_0402; 0402-cap
C14, C61: C_100p_0402; 0402-cap
C15, C29, C64: C_47p_0402; 0402-cap
C16, C17, C18, C34: C_47u_0805; 0805-cap
C21, C22, C23: C_2u2_1206; 1206-cap
C25: C_4n7_0402; 0402-cap
C28, C32, C66: C_1u_0402; 0402-cap
C31: 100u; 1206
C35, C47, C56, C58, C60, C63: C_10u_0603; 0603-cap
C41: C_47n_0402; 0402-cap
C55, C57, C59, C65, C67: C_2u2_0402; 0402-cap
D1: PDS760-13; PowerDI
D2, D4, D13, D14, D17: 1N4148WS; SOD-323
D3, D5, D8, D9, D10, D11, D12: TPD2E009DBZR; SOT-23s
D6, D7: TPD4E05U06_PASS
D15: diode; SOD-323
F1: Fuse-1206
FAN1: molex_2223-2021
IC1: TCA9548ARGER; VQFN-24
IC2, IC18: SON-15
IC3: TPS54561; WSON-10_4x4
IC4, IC15: TLV70018DCKT; SC70-5
IC5: QFN-32
IC6: PCA9517ADP; MSOP-8
IC7: HD3SS3220; RNH0030A
IC8, IC9: LM3671MF-3.3; SOT23-5N
IC10: TPS62823DLCT; TPS62823
IC11: SN74LV1T125DCKR; SC70-5
IC12: 74HC00PW; TSSOP-14
IC13: SN74LVC1G126DCKR; R-PDSO-G5
IC16: NCP380HSNAJAAT1G; TSOP-6
IC17: AT24CS01-ST; SOT23-5
J1: 685119136923; WE_685119136923
J2: 2129320-3
J3: WE_7499110124
J4: DC_SOCKET
J5, J9: CON-Molex-047346-0001
J6: WE_68715014522; WE_68715014522_ONE-SIDE
J7: WE_68715014022
J8: MDT580M01001
J10: PCA-10
J11: 632723300011; WE_632723300011
L1: WE_7447798720
L2, L3: BLM18EG221SN1D; 0603
L4, L6: LQH32PN2R2NN0L
L5: IHLP1212AEERR47M11; IHLP-1212AE
L7, L8, L9, L10: BLM18SG121TN1D; 0603
LED1: LED0603
M1: jetson-nano-connector
M2: jetson-nano-module
NVME1: LED0603
PWR1: LED0603
Q1: PMV32UP; SOT-23s
R1, R2, R3, R4, R7, R8, R9, R10: R_5R6_0402; 0402-res
R5, R6, R11, R18, R22, R24, R25, R27, R28, R29, R33, R34, R35, R37, R55, R69, R70, R73, R81, R83, R88: R_2k_0402; 0402-res
R12, R13, R15, R17, R19, R21, R23, R39, R42, R47, R49, R56, R57, R58, R59, R60, R61, R62, R63, R64, R65, R66, R68, R71, R75, R78, R79, R80, R82, R89, R91, R92, R98, R99, R103, R104, R105, R106, R107, R108, R109, R110, R130, R132: R_0R_0402; 0402-res
R14, R43, R97, R111: R_470R_0402; 0402-res
R16, R36, R87: R_1k_0402; 0402-res
R20, R41: R_22R_0402; 0402-res
R26, R30, R77, R100, R101: R_100k_0402; 0402-res
R31, R32: R_1M0_0402; 0402-res
R38, R40, R128: R_220R_0402; 0402-res
R44, R134: R_243k_0402; 0402-res
R45: R_49R9_0402; 0402-res
R46, R135: R_53k6_0402; 0402-res
R48: R_16k9_0402; 0402-res
R50: 10k2; 0402
R51: R_909k_0402; 0402-res
R52: R_10k2_0402; 0402-res
R53, R67, R84, R86: R_200k_0402; 0402-res
R54, R72, R76, R90, R93, R94, R95, R96, R102, R114, R115, R116, R131: R_10k_0402; 0402-res
R85: R_470k_0402; 0402-res
R112: R_110k_0603; 0603-res
R113: 100k; 0402
REC1: TL3340AF160QG
RST1: TL3340AF160QG
SP1, SP2, SP3, SP4, SP5, SP6: 9774060151; M2.5-6mm
SP7: 9774040151; M2.5-4mm
T1, T2, T3, T4, T5, T6: BSS138APW; SC70-3
TP1, TP2, TP3, TP4, TP5, TP6, TP7, TP9, TP10, TP11, TP12, TP13, TP14, TP16, TP17, TP18, TP19, TP20, TP21, TP22, TP23, TP24, TP25, TP26, TP27, TP28, TP29, TP31, TP32, TP33, TP34, TP35, TP36, TP37, TP38, TP39, TP40, TP41, TP42, TP43, TP44, TP45, TP47: TP-R-1.5
TP30: TC2030
USER1: LED0603
USR1: TL3340AF160QG

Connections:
1V8_DBG: C66.2, IC5.1, IC15.5
1V8_SYS: C5.1, C28.2, IC4.5, IC11.5, R23.2, R79.2, R88.1, R112.2, R114.2, TP47.1
3V3_FFC1: C58.2, IC9.4, J6.47, J6.48, L6.2, R78.2, TP45.1
3V3_FFC2: C56.2, IC8.4, J7.47, J7.48, L4.2, R80.2, TP43.1
3V3_SYS: C9.1, C26.1, C33.1, C36.2, C46.2, C47.2, C60.2, C61.2, D15.A, IC1.21, IC6.1, IC7.8, J8.2, J8.4, J8.12, J8.14, J8.16, J8.18, J8.70, J8.72, J8.74, J10.1, L5.2, L10.1, R11.1, R34.1, R35.1, R38.2, R39.2, R40.1, R53.2, R69.1, R70.1, R81.1, R115.2, R116.2, R128.2, R134.1, TP41.1
5V0_DBG: C67.2, C72.2, D17.C, IC5.19, IC15.1, IC15.3, L3.2
5V0_SYS: C16.2, C17.2, C18.2, C32.2, C34.2, C55.2, C57.2, C59.2, C65.2, C71.2, D14.C, D17.A, F1.1, FAN1.1, IC2.13, IC2.15, IC4.1, IC7.30, IC8.1, IC9.1, IC10.7, IC12.14, IC13.1, IC13.5, IC16.1, J6.49, J6.50, J7.49, J7.50, L1.2, L9.1, Q1.2, R14.2, R16.1, R36.1, R42.1, R43.2, R45.2, R47.2, R54.1, R55.1, R67.2, R71.1, R75.2, R77.2, R84.2, R86.2, R89.2, R91.2, R92.1, R97.2, R101.2, R111.2, TP42.1
#MOD_SLEEP: M1.178, R95.2
#PWR_BUTTON: M1.240, TP31.1
#RECOVERY: M1.214, REC1.2, TP39.1
#RESET: M1.239, R76.2, R90.2, R93.2, R94.2, R96.2, RST1.2, T2.1, TP29.1, TP37.1
#SHUTDOWN_REQ: IC12.4, M1.233, R86.1, TP28.1
/CSI/CAM0_SCL: J6.40, R15.1, R24.2
/CSI/CAM0_SDA: J6.39, R13.1, R25.2
/CSI/CAM1_SCL: J6.42, R18.2, R21.1
/CSI/CAM1_SDA: J6.41, R17.1, R22.2
/CSI/CAM2_SCL: J7.42, R27.2, R58.1
/CSI/CAM2_SDA: J7.41, R19.1, R28.2
/CSI/CAM3_SCL: J7.40, R33.2, R61.1
/CSI/CAM3_SDA: J7.39, R29.2, R59.1
/CSI/CAM_I2C_SCL: M1.213, R35.2, R60.2, TP10.1
/CSI/CAM_I2C_SDA: M1.215, R34.2, R57.2, TP1.1
/CSI/CSI_A_CLK_N: J7.28, M1.10
/CSI/CSI_A_CLK_P: J7.29, M1.12
/CSI/CSI_A_D0_N: J7.25, M1.4
/CSI/CSI_A_D0_P: J7.26, M1.6
/CSI/CSI_A_D1_N: J7.23, M1.16
/CSI/CSI_A_D1_P: J7.24, M1.18
/CSI/CSI_B_D0_N: J7.21, M1.3
/CSI/CSI_B_D0_P: J7.22, M1.5
/CSI/CSI_B_D1_N: J7.19, M1.15
/CSI/CSI_B_D1_P: J7.20, M1.17
/CSI/CSI_C_CLK_N: J7.10, M1.52
/CSI/CSI_C_CLK_P: J7.11, M1.54
/CSI/CSI_C_D0_N: J7.7, M1.46
/CSI/CSI_C_D0_P: J7.8, M1.48
/CSI/CSI_C_D1_N: J7.5, M1.58
/CSI/CSI_C_D1_P: J7.6, M1.60
/CSI/CSI_D_D0_N: J7.3, M1.40
/CSI/CSI_D_D0_P: J7.4, M1.42
/CSI/CSI_D_D1_N: J7.1, M1.64
/CSI/CSI_D_D1_P: J7.2, M1.66
/CSI/CSI_E_CLK_N: J6.28, M1.28
/CSI/CSI_E_CLK_P: J6.29, M1.30
/CSI/CSI_E_D0_N: J6.25, M1.22
/CSI/CSI_E_D0_P: J6.26, M1.24
/CSI/CSI_E_D1_N: J6.23, M1.34
/CSI/CSI_E_D1_P: J6.24, M1.36
/CSI/CSI_F_D0_N: J6.21, M1.21
/CSI/CSI_F_D0_P: J6.22, M1.23
/CSI/CSI_F_D1_N: J6.19, M1.33
/CSI/CSI_F_D1_P: J6.20, M1.35
/CSI/CSI_G_CLK_N: J6.10, M1.76
/CSI/CSI_G_CLK_P: J6.11, M1.78
/CSI/CSI_G_D0_N: J6.7, M1.70
/CSI/CSI_G_D0_P: J6.8, M1.72
/CSI/CSI_G_D1_N: J6.5, M1.82
/CSI/CSI_G_D1_P: J6.6, M1.84
/Display/DP_CEC: J2.6, R32.2
/Display/DP_HPD: IC11.4, M1.88
/Display/DP_HPD_IN: D12.2, IC11.2, J2.2, R100.2
/Display/DP_MODE: J2.4, R31.2
/Display/EDP0_TX_N: C40.1, M1.39
/Display/EDP0_TX_P: C39.1, M1.41
/Display/EDP1_TX_N: C43.1, M1.45
/Display/EDP1_TX_P: C42.1, M1.47
/Display/EDP2_TX_N: C7.1, M1.51
/Display/EDP2_TX_P: C6.1, M1.53
/Display/EDP3_TX_N: C12.1, M1.57
/Display/EDP3_TX_P: C8.1, M1.59
/Display/EDP_AUX_N: C45.1, M1.90
/Display/EDP_AUX_P: C44.1, M1.92
/Display/EDP_C_AUX_C_N: C45.2, J2.18, R26.1
/Display/EDP_C_AUX_C_P: C44.2, J2.16, R30.2
/Display/ML_C_LANE0_N: C40.2, IC2.3, J2.5
/Display/ML_C_LANE0_P: C39.2, IC2.1, J2.3
/Display/ML_C_LANE1_N: C43.2, IC2.6, J2.11
/Display/ML_C_LANE1_P: C42.2, IC2.4, J2.9
/Display/ML_C_LANE2_N: C7.2, IC2.9, J2.17
/Display/ML_C_LANE2_P: C6.2, IC2.7, J2.15
/Display/ML_C_LANE3_N: C12.2, IC2.12, J2.12
/Display/ML_C_LANE3_P: C8.2, IC2.10, J2.10
/Display/TMDS_C1_CLK_N: C80.2, IC18.12, R10.1
/Display/TMDS_C1_CLK_P: C78.2, IC18.10, R9.1
/Display/TMDS_C1_D0_N: C79.2, IC18.9, R8.1
/Display/TMDS_C1_D0_P: C76.2, IC18.7, R7.1
/Display/TMDS_C1_D1_N: C77.2, IC18.6, R4.1
/Display/TMDS_C1_D1_P: C75.2, IC18.4, R3.1
/Display/TMDS_C1_D2_N: C74.2, IC18.3, R2.1
/Display/TMDS_C1_D2_P: C73.2, IC18.1, R1.1
/Display/TMDS_CEC: M1.94, TP26.1
/Display/TMDS_CEC_IN: D11.2, J1.14, R37.1
/Display/TMDS_CLK_C_N: J1.12, R10.2
/Display/TMDS_CLK_C_P: J1.11, R9.2
/Display/TMDS_CLK_N: C80.1, M1.81
/Display/TMDS_CLK_P: C78.1, M1.83
/Display/TMDS_D0_C_N: J1.9, R8.2
/Display/TMDS_D0_C_P: J1.8, R7.2
/Display/TMDS_D0_N: C79.1, M1.75
/Display/TMDS_D0_P: C76.1, M1.77
/Display/TMDS_D1_C_N: J1.6, R4.2
/Display/TMDS_D1_C_P: J1.5, R3.2
/Display/TMDS_D1_N: C77.1, M1.69
/Display/TMDS_D1_P: C75.1, M1.71
/Display/TMDS_D2_C_N: J1.3, R2.2
/Display/TMDS_D2_C_P: J1.2, R1.2
/Display/TMDS_D2_N: C74.1, M1.63
/Display/TMDS_D2_P: C73.1, M1.65
/Display/TMDS_HPD_IN: D11.1, J1.19, R82.1
/Display/TMDS_SCL: M1.100, R98.2, TP33.1
/Display/TMDS_SCL_5V0: D10.2, IC6.7, J1.15, R5.2
/Display/TMDS_SDA: M1.98, R99.2, TP34.1
/Display/TMDS_SDA_5V0: D10.1, IC6.6, J1.16, R6.2
/ID Serial/EEPROM_PWR: D15.C, IC17.4, TP30.1
/ID Serial/SN_WP: IC17.5, R132.1
/Interfaces/C_PCIE0_TX0_N: C38.1, J8.47
/Interfaces/C_PCIE0_TX0_P: C37.1, J8.49
/Interfaces/C_PCIE0_TX1_N: C51.1, J8.35
/Interfaces/C_PCIE0_TX1_P: C49.1, J8.37
/Interfaces/C_PCIE0_TX2_N: C68.1, J8.23
/Interfaces/C_PCIE0_TX2_P: C52.1, J8.25
/Interfaces/C_PCIE0_TX3_N: C70.1, J8.11
/Interfaces/C_PCIE0_TX3_P: C69.1, J8.13
/SoM/PMIC_BBAT: BAT1.+, M1.235
/SoM/USR_BUTTON: M1.208, R112.1, TP36.1, USR1.2
/SoM/USR_LED: M1.230, R113.1, T5.1, TP35.1
/Supply/Q: D13.C, IC12.3, IC12.5, R36.2, R85.1
/Supply/QDEL: C63.2, D13.A, IC12.12, IC12.13, IC13.2, R85.2, R87.2
/Supply/\~PWR_SET~: C41.2, IC12.1, R84.1
/USB/CC1: IC7.2, R63.1, R66.2
/USB/CC2: IC7.1, R64.1, R65.2
/USB/C_CC1: D5.2, J11.A5, R63.2, R64.2
/USB/C_CC2: D5.1, J11.B5, R65.1, R66.1
/USB/C_USBSS_RX1_N: D6.1, J11.B10, R104.2
/USB/C_USBSS_RX1_P: D6.2, J11.B11, R106.2
/USB/C_USBSS_RX2_N: D7.5, J11.A10, R109.2
/USB/C_USBSS_RX2_P: D7.4, J11.A11, R110.2
/USB/C_USBSS_RX6_N: IC7.10, R108.2
/USB/C_USBSS_RX6_P: IC7.9, R107.2
/USB/C_USBSS_TX1_N: C48.1, D6.5, J11.A3
/USB/C_USBSS_TX1_P: C50.1, D6.4, J11.A2
/USB/C_USBSS_TX2_N: C53.1, D7.2, J11.B3
/USB/C_USBSS_TX2_P: C54.1, D7.1, J11.B2
/USB/C_USBSS_TX6_N: IC7.7, R105.2
/USB/C_USBSS_TX6_P: IC7.6, R103.2
/USB/DBG_USB_D_N: C29.2, D3.1, IC5.15, J9.2
/USB/DBG_USB_D_P: C15.2, D3.2, IC5.14, J9.3
/USB/EN_MUX: IC7.12, R56.2, R68.1
/USB/USBC_ADDR: IC7.22, TP21.1
/USB/USBC_FAULT: IC7.24, TP32.1
/USB/USBC_ID: IC7.27, Q1.1, R68.2, R101.1, TP18.1
/USB/USBC_INTN: IC7.23, R67.1
/USB/USBC_SCL: IC7.26, R70.2
/USB/USBC_SDA: IC7.25, R69.2
/USB/USBSS_RX1_N: IC7.14, R104.1
/USB/USBSS_RX1_P: IC7.15, R106.1
/USB/USBSS_RX2_N: IC7.18, R109.1
/USB/USBSS_RX2_P: IC7.19, R110.1
/USB/USBSS_TX1_N: C48.2, IC7.16
/USB/USBSS_TX1_P: C50.2, IC7.17
/USB/USBSS_TX2_N: C53.2, IC7.20
/USB/USBSS_TX2_P: C54.2, IC7.21
DP_PWR: D2.A, L10.2, R26.2
EGND: C14.1, J3.S, SP4.1
ENET_LED0: J3.14, M1.194
ENET_LED1: J3.12, M1.188
ENET_TRD0_N: J3.1, M1.184
ENET_TRD0_P: J3.2, M1.186
ENET_TRD1_N: J3.3, M1.190
ENET_TRD1_P: J3.4, M1.192
ENET_TRD2_N: J3.7, M1.196
ENET_TRD2_P: J3.8, M1.198
ENET_TRD3_N: J3.9, M1.202
ENET_TRD3_P: J3.10, M1.204
GEN0_SCL: IC17.1, M1.185, TP23.1, TP30.4
GEN0_SDA: IC17.3, M1.187, TP24.1, TP30.3, TP30.6
GND: BAT1.-, C1.1, C2.1, C3.1, C4.1, C5.2, C9.2, C10.2, C11.2, C13.2, C14.2, C15.1, C16.1, C17.1, C18.1, C21.1, C22.1, C23.1, C24.2, C25.1, C26.2, C27.1, C28.1, C29.1, C30.1, C31.1, C32.1, C33.2, C34.1, C35.1, C36.1, C41.1, C46.1, C47.1, C55.1, C56.1, C57.1, C58.1, C59.1, C60.1, C62.1, C63.1, C64.1, C65.1, C66.1, C67.1, C71.1, C72.1, D1.A, D3.3, D5.3, D6.3, D6.8, D7.3, D7.8, D8.3, D9.3, D10.3, D11.3, D12.3, IC1.9, IC1.18, IC1.22, IC1.23, IC2.2, IC2.5, IC2.8, IC2.11, IC3.8, IC3.11, IC4.2, IC5.4, IC5.17, IC5.20, IC5.24, IC5.26, IC6.4, IC7.13, IC7.28, IC7.31, IC8.2, IC9.2, IC10.3, IC10.5, IC11.1, IC11.3, IC12.7, IC13.3, IC15.2, IC16.2, IC17.2, IC18.2, IC18.5, IC18.8, IC18.11, J2.1, J2.7, J2.8, J2.13, J2.14, J2.19, J2.21, J2.22, J2.23, J2.24, J4.2, J4.3, J5.5, J5.S, J6.9, J6.12, J6.15, J6.18, J6.27, J6.30, J7.9, J7.12, J7.15, J7.18, J7.27, J7.30, J8.1, J8.3, J8.9, J8.15, J8.21, J8.27, J8.33, J8.39, J8.45, J8.51, J8.57, J8.71, J8.73, J8.75, J8.SH1, J8.SH2, J9.5, J9.S, J10.10, J11.A1, J11.A12, J11.B1, J11.B12, J11.Shell, L7.1, L7.2, L8.1, M1.1, M1.2, M1.7, M1.8, M1.13, M1.14, M1.19, M1.20, M1.25, M1.26, M1.31, M1.32, M1.37, M1.38, M1.43, M1.44, M1.49, M1.50, M1.55, M1.56, M1.61, M1.62, M1.67, M1.68, M1.73, M1.74, M1.79, M1.80, M1.85, M1.86, M1.102, M1.107, M1.113, M1.119, M1.125, M1.129, M1.132, M1.135, M1.138, M1.141, M1.144, M1.146, M1.147, M1.152, M1.153, M1.158, M1.159, M1.164, M1.165, M1.170, M1.171, M1.176, M1.177, M1.200, M1.201, M1.217, M1.231, M1.241, M1.242, M1.243, M1.244, M1.245, M1.246, M1.247, M1.248, M1.249, M1.250, M1.261, M1.262, R12.1, R30.1, R31.1, R32.1, R37.2, R44.2, R50.1, R52.1, R56.1, R62.1, R73.2, R83.2, R100.1, R102.1, R113.2, R131.1, R135.1, REC1.1, REC1.3, REC1.SH1, REC1.SH2, RST1.1, RST1.3, RST1.SH1, RST1.SH2, SP1.1, SP2.1, SP3.1, SP5.1, SP6.1, SP7.1, T1.2, T2.2, T3.2, T4.2, T5.2, T6.2, TP17.1, TP30.5, TP44.1, USR1.1, USR1.3, USR1.SH1, USR1.SH2
HDMI_PWR: C27.2, D4.A, IC6.5, IC6.8, IC18.13, IC18.15, L9.2, R5.1, R6.1
HDMI_SHIELD: J1.1, J1.4, J1.7, J1.10, J1.Shell, L8.2
M2_ALERT: J8.44, M1.212, R114.1, TP2.1
unnamed: BOOT1.A, R14.1
unnamed: BOOT1.K, T2.3
unnamed: C1.2, C2.2, D4.C, J1.18
unnamed: C3.2, C4.2, D2.C, J2.20
unnamed: C13.1, J3.5, J3.6
unnamed: C19.1, IC3.1
unnamed: C19.2, D1.C, IC3.9, L1.1
unnamed: C24.1, IC3.4
unnamed: C25.2, R48.1
unnamed: C30.2, IC5.16
unnamed: C31.2, IC16.6, L2.1
unnamed: C61.1, IC10.2, R134.2, R135.2
unnamed: C62.2, D9.1, D9.2, J5.1, R71.2, R72.1
unnamed: C64.2, IC3.7, R48.2
unnamed: D14.A, FAN1.2, T3.3
unnamed: IC1.1, R13.2
unnamed: IC1.2, R15.2
unnamed: IC1.3, R17.2
unnamed: IC1.4, R21.2
unnamed: IC1.5, R19.2
unnamed: IC1.6, R58.2
unnamed: IC1.7, R59.2
unnamed: IC1.8, R61.2
unnamed: IC1.10, TP11.1
unnamed: IC1.11, TP12.1
unnamed: IC1.19, R60.1
unnamed: IC1.20, R57.1
unnamed: IC1.24, R39.1
unnamed: IC3.3, TP5.1
unnamed: IC3.5, R44.1
unnamed: IC3.6, R46.1, R52.2
unnamed: IC4.3, R92.2, R94.1
unnamed: IC5.2, R41.1
unnamed: IC5.30, R20.1
unnamed: IC6.2, R81.2, R98.1
unnamed: IC6.3, R11.2, R99.1
unnamed: IC7.3, R54.2
unnamed: IC7.4, R55.2
unnamed: IC7.5, R51.1
unnamed: IC7.11, R53.1
unnamed: IC7.29, R62.2
unnamed: IC8.3, R89.1, R90.1
unnamed: IC8.6, L4.1
unnamed: IC9.3, R91.1, R93.1
unnamed: IC9.6, L6.1
unnamed: IC10.1, R75.1, R76.1
unnamed: IC10.6, L5.1
unnamed: IC12.2, IC12.6, R16.2
unnamed: IC12.8, R130.2
unnamed: IC12.9, IC12.10, IC12.11
unnamed: IC16.3, R47.1, R49.2, R102.2
unnamed: IC16.4, LED1.K
unnamed: IC16.5, R50.2
unnamed: J1.13, R12.2
unnamed: J3.11, R38.1
unnamed: J3.13, R40.2
unnamed: J5.4, TP22.1
unnamed: J8.10, NVME1.K
unnamed: J8.40, TP20.1
unnamed: J8.42, TP7.1
unnamed: J9.1, L3.1
unnamed: J11.B8, TP19.1
unnamed: LED1.A, R43.1
unnamed: M1.9, TP3.1
unnamed: M1.11, TP4.1
unnamed: M1.118, TP9.1
unnamed: M1.120, TP6.1
unnamed: M1.206, TP13.1
unnamed: M1.218, TP14.1
unnamed: NVME1.A, R128.1
unnamed: PWR1.A, R97.1
unnamed: PWR1.K, T4.3
unnamed: Q1.3, R49.1
unnamed: R18.1, R22.1, R23.1, R24.1, R25.1, R78.1
unnamed: R27.1, R28.1, R29.1, R33.1, R79.1, R80.1
unnamed: R45.1, R46.2
unnamed: R72.2, R73.1, T6.1
unnamed: R82.2, R83.1, T1.1
unnamed: R95.1, R96.1, T3.1
unnamed: R111.1, USER1.A
unnamed: R132.2, TP30.2
unnamed: T5.3, USER1.K
OTG_USB_D_N: D8.1, J5.2, M1.109
OTG_USB_D_P: D8.2, J5.3, M1.111
OTG_USB_VBUS: M1.87, T6.3
PCIE0_CLK_N: J8.53, M1.160
PCIE0_CLK_P: J8.55, M1.162
PCIE0_RX0_N: J8.41, M1.131
PCIE0_RX0_P: J8.43, M1.133
PCIE0_RX1_N: J8.29, M1.137
PCIE0_RX1_P: J8.31, M1.139
PCIE0_RX2_N: J8.17, M1.149
PCIE0_RX2_P: J8.19, M1.151
PCIE0_RX3_N: J8.5, M1.155
PCIE0_RX3_P: J8.7, M1.157
PCIE0_TX0_N: C38.2, M1.134
PCIE0_TX0_P: C37.2, M1.136
PCIE0_TX1_N: C51.2, M1.140
PCIE0_TX1_P: C49.2, M1.142
PCIE0_TX2_N: C68.2, M1.148
PCIE0_TX2_P: C52.2, M1.150
PCIE0_TX3_N: C70.2, M1.154
PCIE0_TX3_P: C69.2, M1.156
PCIE1_CLKREQ: J10.3, M1.182
PCIE1_CLK_N: J10.5, M1.173
PCIE1_CLK_P: J10.4, M1.175
PCIE1_RST: J10.2, M1.183
PCIE1_RX0_N: J10.9, M1.167
PCIE1_RX0_P: J10.8, M1.169
PCIE1_TX0_N: J10.7, M1.172
PCIE1_TX0_P: J10.6, M1.174
PEX_L0_CLKREQ_N: J8.52, M1.180, R115.1
PEX_L0_RST_N: J8.50, M1.181, R116.1
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

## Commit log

2019-03-18 Initial commit.
    [Jetson-Nano-Baseboard-v1.0-BOM.ods, SoM.SchDoc, csi.SchDoc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]
2019-04-17 Updated pads for Displayport connector Corrected I2C connection for camera interface Added Q1 that inverts control logic that drives EN pin of IC16 Added pull-down R100 that controls Hotplug signal f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
    [Jetson-Nano-Baseboard-BOM.csv, Jetson-Nano-Baseboard-v1.0-BOM.ods, SoM.SchDoc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]
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2019-09-17 Update schematics with new pinout
    [SoM.SchDoc, csi.SchDoc, display.SchDoc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]
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2020-02-23 Add rev. 1.3
    [Jetson-Nano-Baseboard-BOM.csv, Jetson_Nano_Baseboard-Rev.1.3-bom.csv, Jetson_Nano_Baseboard-Rev.1.3-pnp.csv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]
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2020-03-06 Fix PrjPcb
    [jetson-nano-baseboard.PrjPcb, usb-debug.SchDoc]
2020-03-06 Resolve documentation discrepancy
    [Jetson_Nano_Baseboard-Rev.1.3-bom.csv, SoM.SchDoc, csi.SchDoc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]
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2020-04-21 Remove OutJob from project file
    [SoM.SchDoc, jetson-nano-baseboard.PrjPcb]
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2020-04-21 Update documentation for release 1.4.2
    [Jetson_Nano_Baseboard-Rev.1.3-bom.csv, Jetson_Nano_Baseboard-Rev.1.3-pnp.csv, Jetson_Nano_Baseboard-Rev.1.4.2-bom.csv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]
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2020-10-12 Add documentation for release 1.4.6
    [Jetson_Nano_Baseboard-Rev.1.4.6-bom.csv, Jetson_Nano_Baseboard-Rev.1.4.6-pnp.csv]
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2021-06-04 Move the Altium design files to a separate directory
    [CSI.SchDoc, Display.SchDoc, ID-Serial.SchDoc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]
2021-06-04 Add KiCad counterpart for 1.4.7
    [22232021.stp, 632723300011.stp, 68715014522.stp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]
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2021-06-09 Fix R113 connection
    [som.sch]
2021-06-09 Update 3d models and clean up designators
    [jetson-nano-baseboard.kicad_pcb]
2021-06-09 Fix DRC errors
    [jetson-nano-baseboard.kicad_pcb, usb-debug.sch]
2021-06-09 Add PCB stackup table
    [jetson-nano-baseboard.kicad_pcb]
2021-06-09 Clean up B.SilkS layer
    [jetson-nano-baseboard.kicad_pcb]
2021-06-09 Add logo and clean up libraries
    [jetson-nano-baseboard.sch]
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2021-10-01 Added ferrite beads before DC/DC and SOM
    [som.sch, supply.sch]
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2021-12-31 Clean artifacts, clean space for a new DCDC
    [interfaces.sch, jetson-nano-baseboard.sch, som.sch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]
2021-12-31 Change HDMI connector on schematic
    [display.sch]
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2021-12-31 Changed package of SN74LV1T125 to SOT32
    [display.sch]
2021-12-31 Changed DP connector to micro HDMI on schematic
    [display.sch]
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2021-12-31 Replace NCP380HS with AP22652W6-7
    [usb-debug.sch]
2021-12-31 Move items to fit in borders
    [usb-debug.sch]
2021-12-31 Change TPD2E009DBZR with PESD2USB5UV-TR on schematic
    [display.sch, usb-debug.sch]
2021-12-31 Rotate D9 to fit connections
    [usb-debug.sch]
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2021-12-31 Replace 5V0 and 3V3 DCDC
    [supply.sch]
2021-12-31 Fix symbols, change DCDCC output capacitors to 0805
    [supply.sch]
2021-12-31 Disconnect pin 3 and 12 of LM604x0. Based on layout from datasheet
    [supply.sch]
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2021-12-31 Update comments, move things around on PCB
    [csi.sch, supply.sch]
2021-12-31 Move ethernet connector closet to the edge. Loclib
    [csi.sch, display.sch, interfaces.sch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]
2021-12-31 Fix traces after moving ethernet
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2021-12-31 Rework 3V3 and 5V DCDC on schematic, layout 3V3 DCDC
    [csi.sch, supply.sch]
2021-12-31 Layout 5V DCDC, check traces, fix ffab references size
2021-12-31 Change fan design to match Nvidia. Change user button and led pins
    [display.sch, som.sch, supply.sch]
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2021-12-31 Replace ethernet connector, fix traces and tuning
    [interfaces.sch, usb-debug.sch]
2021-12-31 Bump the design release to 1.5.0
    [CSI.SchDoc, Display.SchDoc, ID-Serial.SchDoc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]
2022-01-03 Change R50 to 12k4
    [usb-debug.sch]
2022-01-03 Update 3V3 passives, add OR resistor to feedback network
    [supply.sch]
2022-01-03 Change IC15 to TPS7A0518, loclib
    [supply.sch, usb-debug.sch]
2022-01-03 Change U3 to SN74LXC1T45DBVR
    [supply.sch]
2022-01-03 Loclib, update schematic 5Vof DCDC and 3V3DCDC for cameras
    [id-serial.sch, interfaces.sch, som.sch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]
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2022-01-03 Finish routing, cleanup silks
    [som.sch, supply.sch]
2022-01-04 Add comment to Usr led and button
    [som.sch]
2022-01-05 Update MPN of U1 and U5 to LM3671MF-3.3/NOPB
    [supply.sch]
2022-01-05 Change BLM18EG221SN1D to BLM18SG121TN1D on schematic and PCB
    [usb-debug.sch]
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2022-01-07 Fix power zone with thermal reliefs, minor silks cleanup
2022-02-03 Update MPS for FB2 FB3
    [som.sch, supply.sch]
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2022-02-03 Fix footprint libraries
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2022-02-04 Assign Rev. 1.5.1 on schematic sheets
    [csi.sch, display.sch, id-serial.sch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]
2022-02-07 Change J10 to 5051101097
    [som.sch]
2022-02-07 Fix annotation on J10
    [som.sch]
2022-02-22 Add LM3671MF-3.3/NOPB to library, change U1 and U5 library reference
    [supply.sch]
2022-02-25 Fix ethernet connector CT and GND connections
    [interfaces.sch]
2022-02-25 Fix connections between resistors and DCDCs
    [supply.sch]
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2022-03-22 Add i2c-mux reset pull-up
    [csi.sch]
2022-04-06 Replace AP22652AW6-7 with AP22653W6-7
    [usb-debug.sch]
2022-04-15 Add logtypes to schematic sheets
    [csi.sch, display.sch, id-serial.sch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]
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2023-05-05 Migrated to KiCAD 6
    [csi.kicad_sch, csi.sch, display.kicad_sch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]
2023-05-05 Added possibility to reset I2C mux from SoM GPIO
    [csi.kicad_sch, jetson-nano-baseboard.kicad_sch, som.kicad_sch]
2023-05-05 Fixed schematic connection between USB OTG shield and L7
    [jetson-nano-baseboard.kicad_sch, usb-debug.kicad_sch]
2023-05-05 Added USB OTG functionality
    [jetson-nano-baseboard.kicad_sch, som.kicad_sch, usb-debug.kicad_sch]
2023-05-05 Replaced 742792022 ferrites with 74279220181 for higher current capability
    [jetson-nano-baseboard.kicad_sch, som.kicad_sch, supply.kicad_sch]
2023-05-05 Added resistor between RBOOT and CBOOT on 3V3_SYS regulator for reduced EMI
    [jetson-nano-baseboard.kicad_sch, supply.kicad_sch]
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2023-05-05 Modified USBC ID logic
    [jetson-nano-baseboard.kicad_sch, usb-debug.kicad_sch]
2023-05-05 Added OR resistors to connect IC7 to I2C bus
    [jetson-nano-baseboard.kicad_sch, usb-debug.kicad_sch]
2023-05-05 Improved input protection - added TVSes, reverse polarity protection and input fuse
    [jetson-nano-baseboard.kicad_sch, supply.kicad_sch]
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2023-05-05 Resolve TOOD on USB sheet
    [csi.kicad_sch, interfaces.kicad_sch, jetson-nano-baseboard.kicad_sch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]
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2023-05-05 Continue placement, mix USB SS signals as HD3SS3220 allows for it
    [interfaces.kicad_sch, jetson-nano-baseboard.kicad_sch, som.kicad_sch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]
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2023-05-05 Fix SIC477ED note
    [supply.kicad_sch]
2023-05-05 Connect OTG VBUS_DET and ID_DET signals to SOM
    [display.kicad_sch, som.kicad_sch]
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2023-05-05 Fix DRC errors. 3 connection TBD
    [jetson-nano-baseboard.kicad_sch]
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2023-05-05 Improve USB-C load switch ctrl circuit
    [jetson-nano-baseboard.kicad_sch, usb-debug.kicad_sch]
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2023-05-05 Replace USB power switches with version without output discharge
    [csi.kicad_sch, display.kicad_sch, id-serial.kicad_sch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]
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2023-05-05 Bumped revision to 1.6.1
    [csi.kicad_sch, display.kicad_sch, id-serial.kicad_sch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]
2023-05-05 Fixed D1 and D9 footprints
    [jetson-nano-baseboard.kicad_sch, supply.kicad_sch]
2023-05-05 Updated loclib and synced it with schematic
    [csi.kicad_sch, display.kicad_sch, id-serial.kicad_sch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]
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2023-05-05 Fix USB-OTG backfeed issue #44022
    [csi.kicad_sch, display.kicad_sch, id-serial.kicad_sch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]
2023-05-05 Add #RESET pull-down
    [jetson-nano-baseboard.kicad_sch, som.kicad_sch]
2023-05-05 ADD U8 to the local library
    [jetson-nano-baseboard.kicad_sch, usb-debug.kicad_sch]
2023-05-05 Replace D5 and D10 with a copy of D12
    [display.kicad_sch, jetson-nano-baseboard.kicad_sch, usb-debug.kicad_sch]
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2023-10-13 50276 Add OHP assets and schematic PDF
    [stackup.csv, symbol_replacement.csv]
2024-04-11 [#56834] Fix components links
    [csi.kicad_sch, display.kicad_sch, id-serial.kicad_sch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]
2024-04-12 [#57913] fix 2309413-1
    [csi.kicad_sch, display.kicad_sch, id-serial.kicad_sch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]
2025-09-18 [#83358] Update KiCad project files
    [csi.kicad_sch, display.kicad_sch, id-serial.kicad_sch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]
2025-09-18 [#83358] Run kmake dnp
    [csi.kicad_sch, display.kicad_sch, supply.kicad_sch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]
2025-09-18 [#83358] Repair broken symbol after update
    [display.kicad_sch, id-serial.kicad_sch, interfaces.kicad_sch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]
2025-09-18 [#83358] Repair broken footprints after symbols update
2025-09-18 [#83366] Remove SoM and Tag Connect from vis
    [id-serial.kicad_sch, som.kicad_sch]
2025-09-18 [#83366] Repair Tag connector shortage
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2025-12-31 [#83366] Remove asset files
    [stackup.csv]
